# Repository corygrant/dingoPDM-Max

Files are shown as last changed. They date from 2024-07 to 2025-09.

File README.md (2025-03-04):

## dingoPDM-Max
dingoPDM-Max is an Infineon Profet based Power Distribution Module. 

# [**Documentation**](https://corygrant.github.io/dingoPDM/)

# [**Store**](https://dingo-electronics.square.site/product/dingopdm-max/9)

## Disclaimer
Please note that this product has been designed by a hobbyist, not a professional. It is intended for off-road and testing use only. Users should operate the product at their own discretion and risk. The designer explicitly disclaims any responsibility for damage or injury that may result from the use of this product.

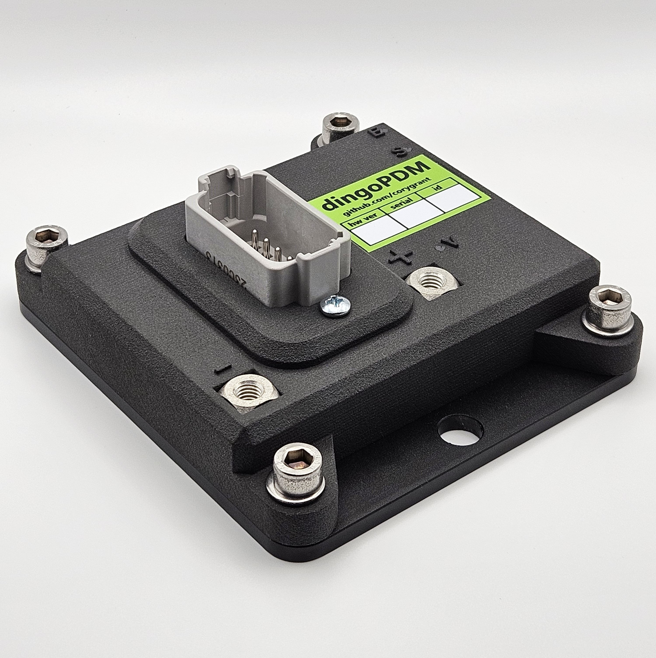
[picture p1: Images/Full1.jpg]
Full1


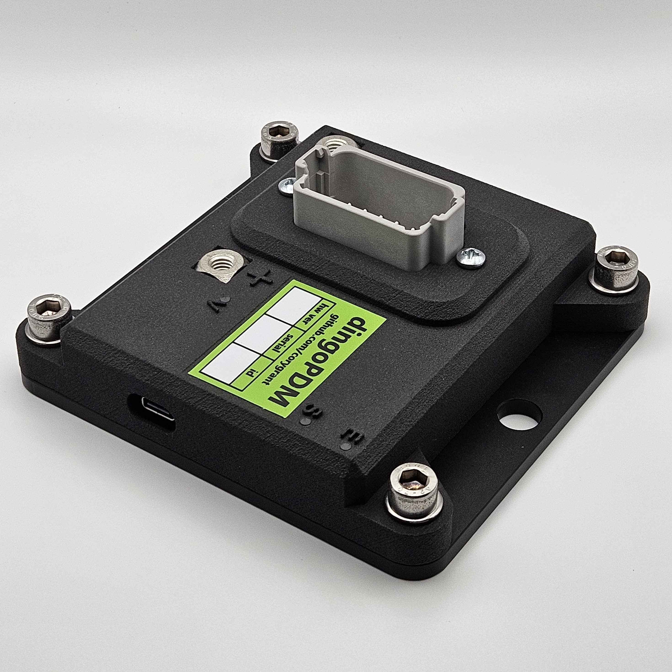
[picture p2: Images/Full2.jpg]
Full2


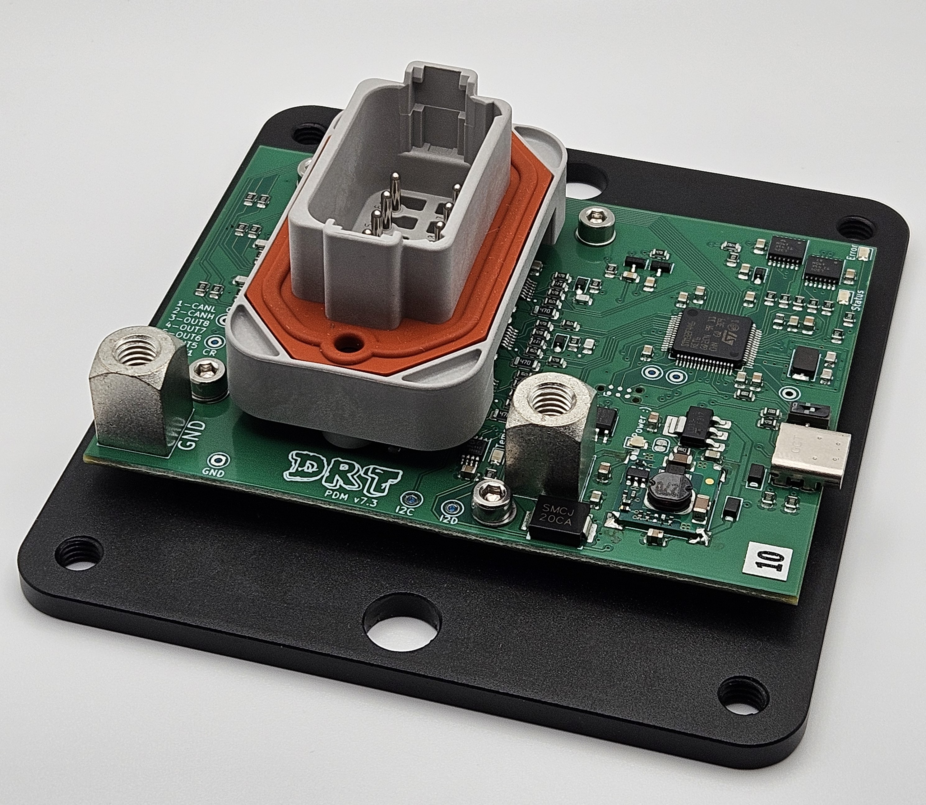
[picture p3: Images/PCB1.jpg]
PCB1


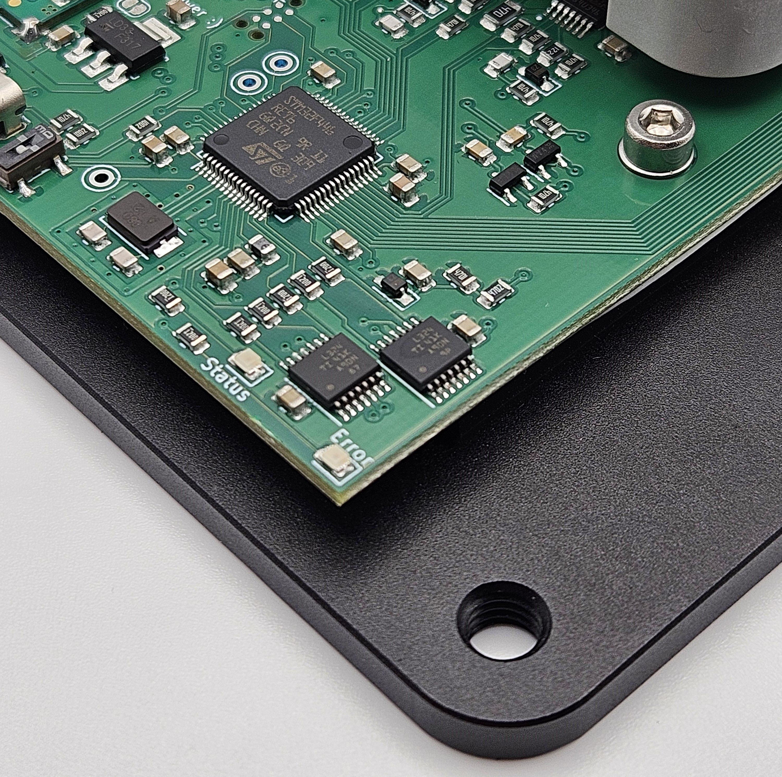
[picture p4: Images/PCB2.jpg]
PCB2


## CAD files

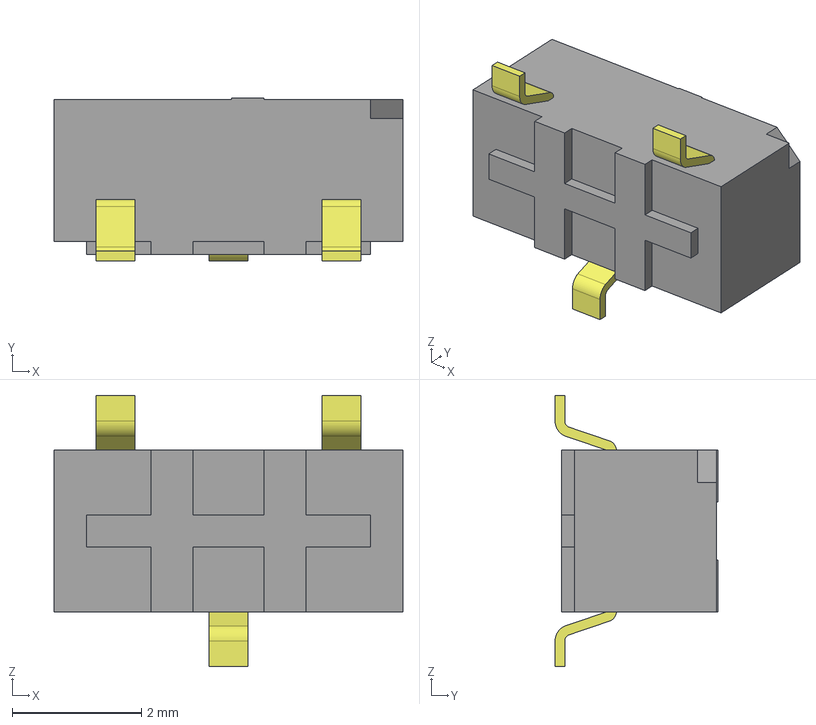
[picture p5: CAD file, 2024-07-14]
dingoPDM-Max/Models/CJS-1200TB.stp
5.40 x 2.52 x 4.20 mm
_CJS_c_12
_CJS Slider_s

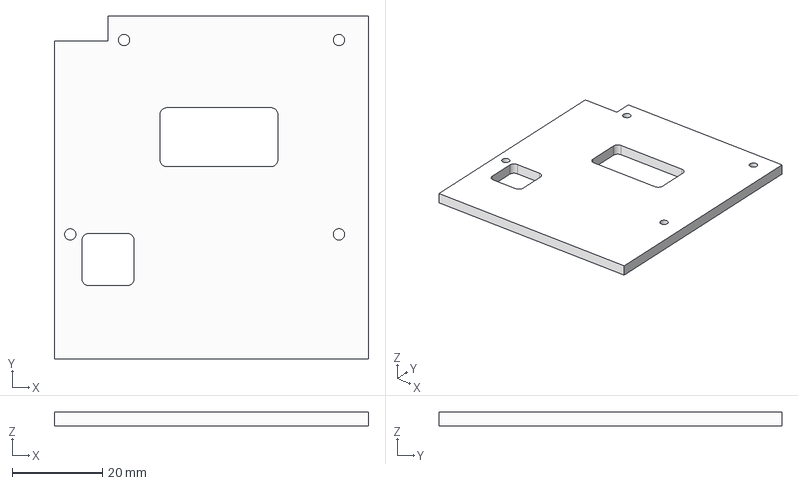
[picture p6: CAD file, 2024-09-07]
Export/V1.2/Case/HeatsinkPlate.step
69.8 x 76.2 x 3.17 mm

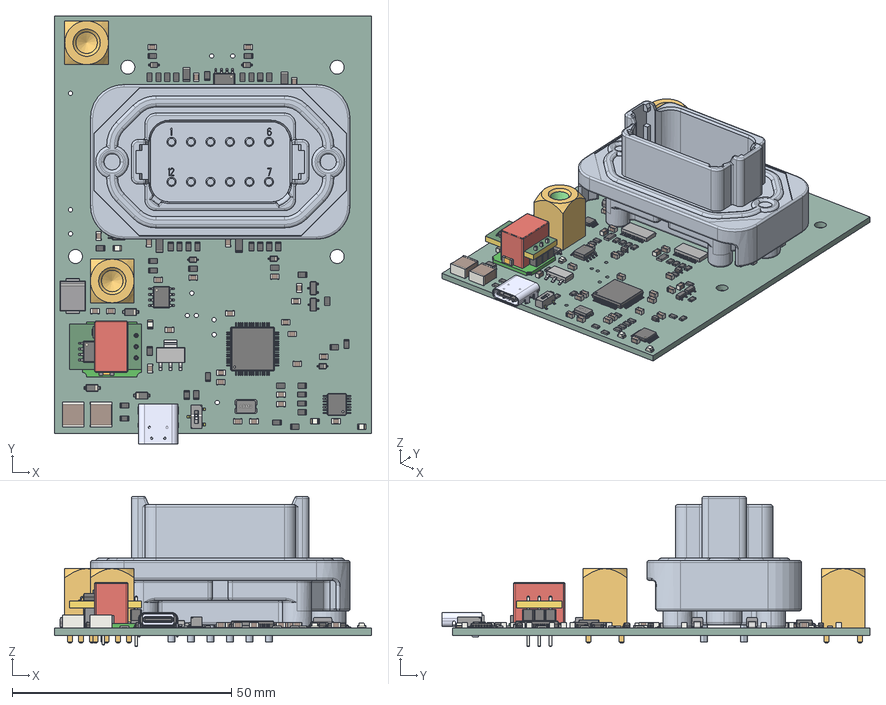
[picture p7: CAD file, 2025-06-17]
Export/V1.2/dingoPDM-Max_V1_2.step
72.4 x 97.6 x 34.3 mm
R_0805_2012Metric x 41
SOIC-8_3.9x4.9mm_P1.27mm x 2
ABM3
C_0805_2012Metric x 38
7461084_Download_STP_7461084_rev1 x 2
MSOP-8_3x3mm_P0.65mm
D_SOD-323 x 5
PG-TSDSO-24-32 x 4
LQFP-64_10x10mm_P0.5mm
c-dt15-12pa-e-3d
CUI_VXO7805-500-M
LED_0805_2012Metric x 4
User Library-SOT23-3
SOT-23 x 2
C_2220_5750Metric x 2
User Library-DO-214AC SMA x 4
USB4085-GF-A--3DModel-STEP-56544
Converter_DCDC_Murata_OKI-78SR_Horizontal
R_1206_3216Metric x 4
D_SOD-123 x 3
User Library-sot-223
User Library-DO-214AB SMC
_CJS_c_12
_CJS Slider_s
Converter_DCDC_TRACO_TSR-1_THT
TSSOP-14_4.4x5mm_P0.65mm
dingoPDM-Max_PCB

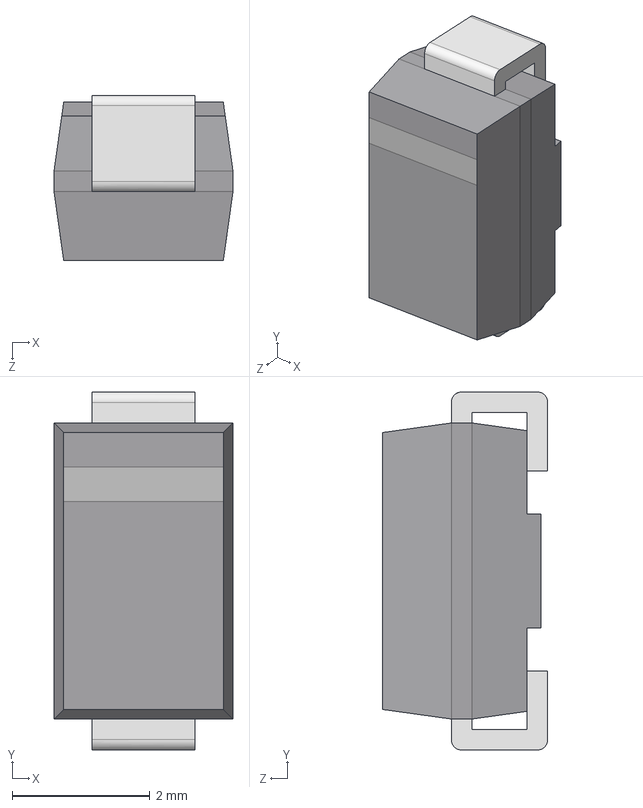
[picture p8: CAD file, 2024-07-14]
dingoPDM-Max/Models/User Library-DO-214AC SMA.STEP
2.60 x 5.20 x 2.40 mm

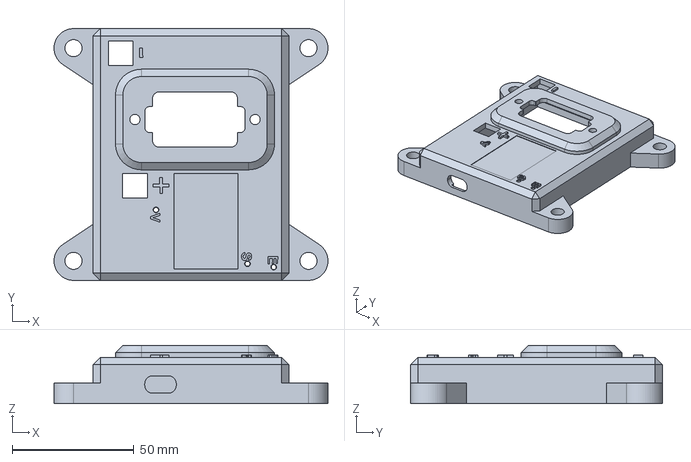
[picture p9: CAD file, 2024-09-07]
Export/V1.2/Case/Case.step
112.4 x 103.3 x 23.9 mm

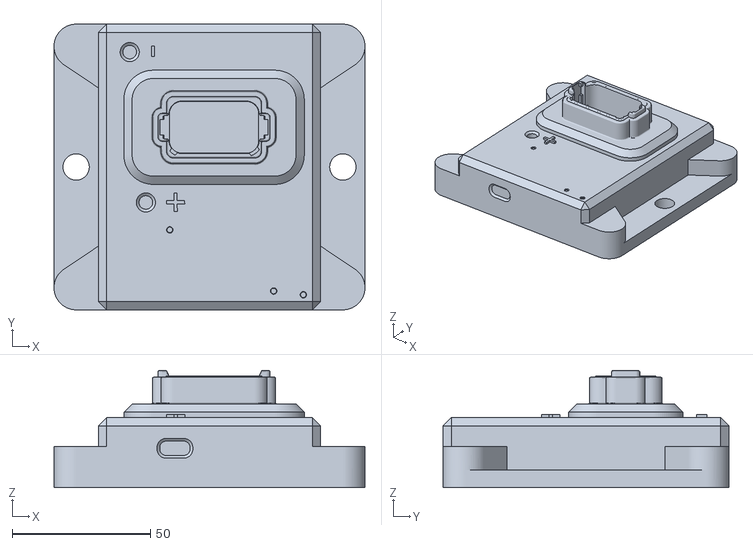
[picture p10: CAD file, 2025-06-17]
Export/V1.2/DingoPDM_V7_WiringAid.stl
112.4 x 103.2 x 42.3

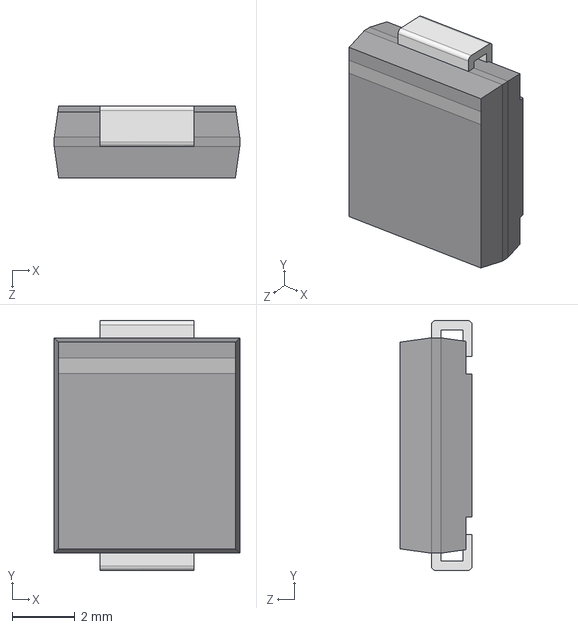
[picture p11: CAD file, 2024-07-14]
dingoPDM-Max/Models/User Library-DO-214AB SMC.STEP
5.90 x 7.95 x 2.30 mm

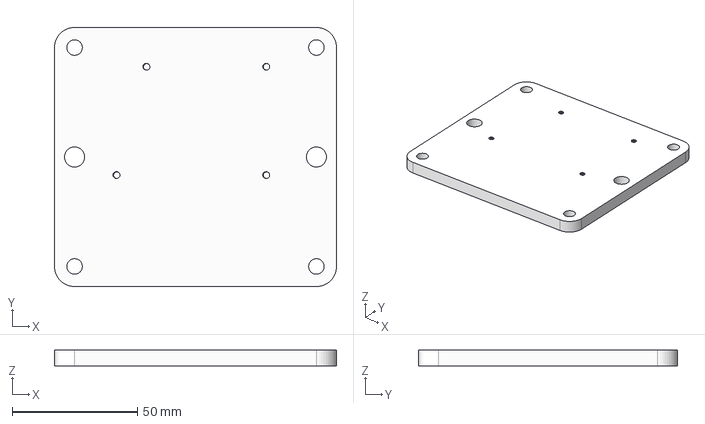
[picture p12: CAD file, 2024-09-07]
Export/V1.2/Case/Baseplate.step
112.4 x 103.2 x 6.35 mm

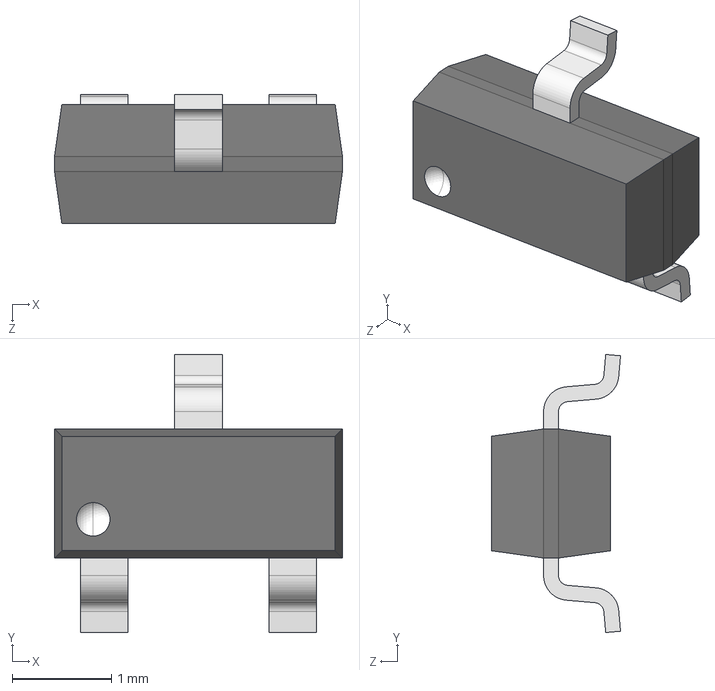
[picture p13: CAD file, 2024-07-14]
dingoPDM-Max/Models/User Library-SOT23-3.step
2.90 x 2.80 x 1.30 mm

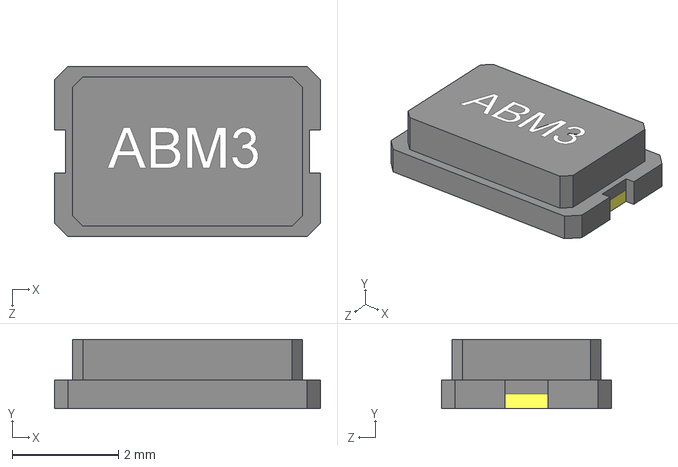
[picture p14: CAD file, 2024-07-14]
dingoPDM-Max/Models/ABM3.STEP
5.00 x 1.30 x 3.20 mm

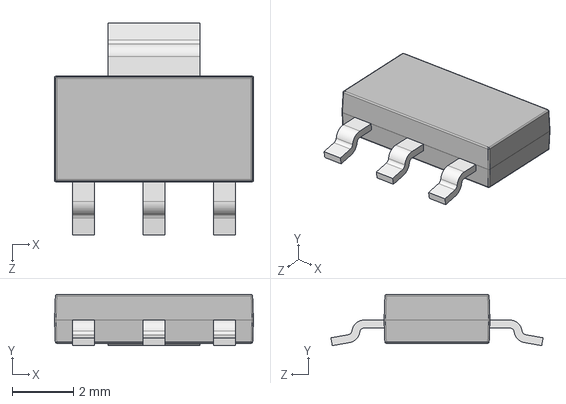
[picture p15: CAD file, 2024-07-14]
dingoPDM-Max/Models/User Library-sot-223.STEP
6.50 x 1.67 x 6.93 mm

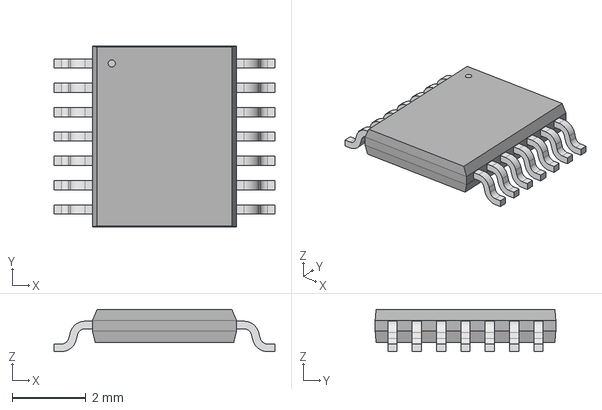
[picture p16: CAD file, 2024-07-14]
dingoPDM-Max/Models/PG-TSDSO-14_INF.step
5.99 x 4.90 x 1.15 mm

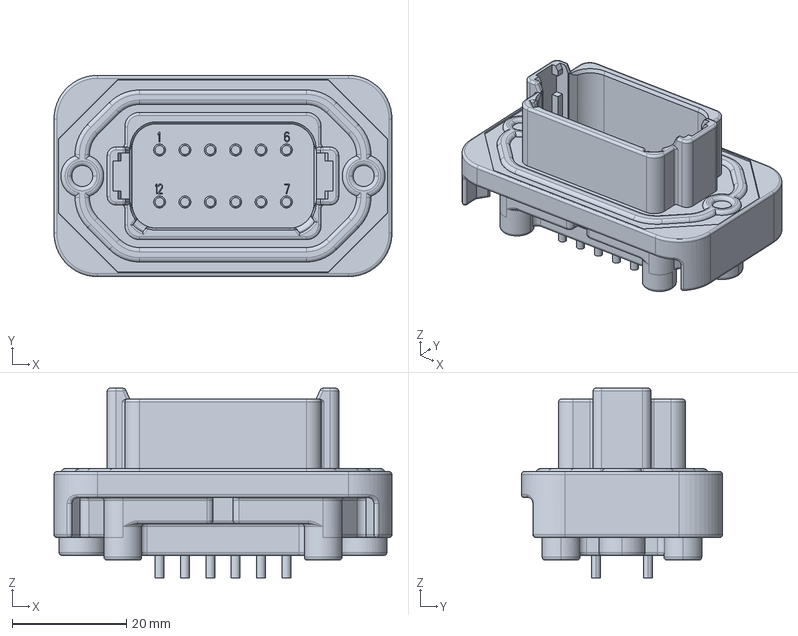
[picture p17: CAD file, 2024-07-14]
dingoPDM-Max/Models/c-dt15-12pa-e-3d.stp
59.2 x 35.3 x 33.2 mm

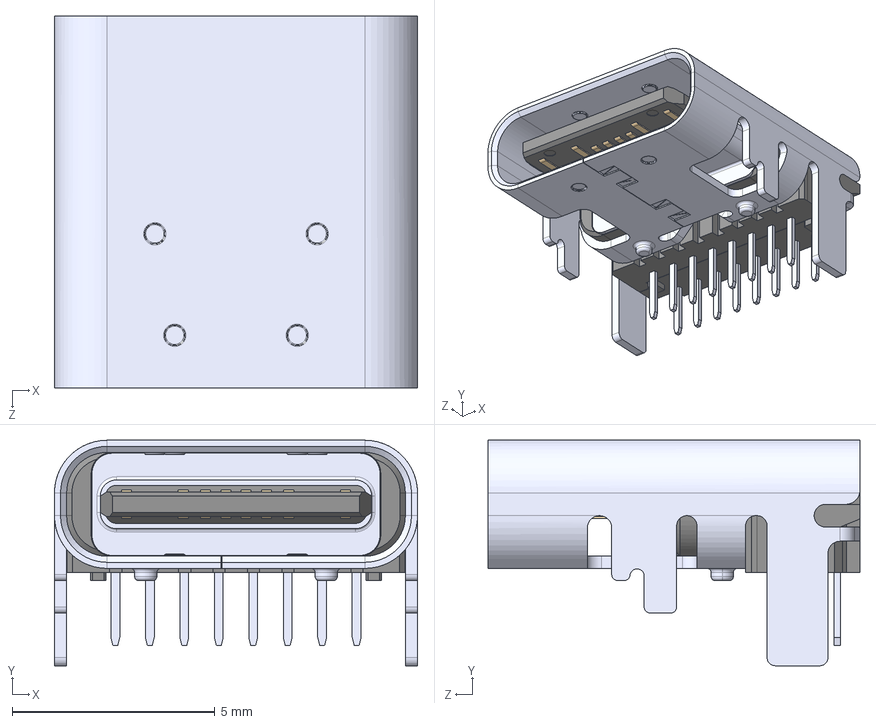
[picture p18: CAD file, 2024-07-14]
dingoPDM-Max/Models/USB4085-GF-A--3DModel-STEP-56544.STEP
8.95 x 5.56 x 9.17 mm

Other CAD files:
dingoPDM-Max/Models/7461084_Download_STP_7461084_rev1.stp

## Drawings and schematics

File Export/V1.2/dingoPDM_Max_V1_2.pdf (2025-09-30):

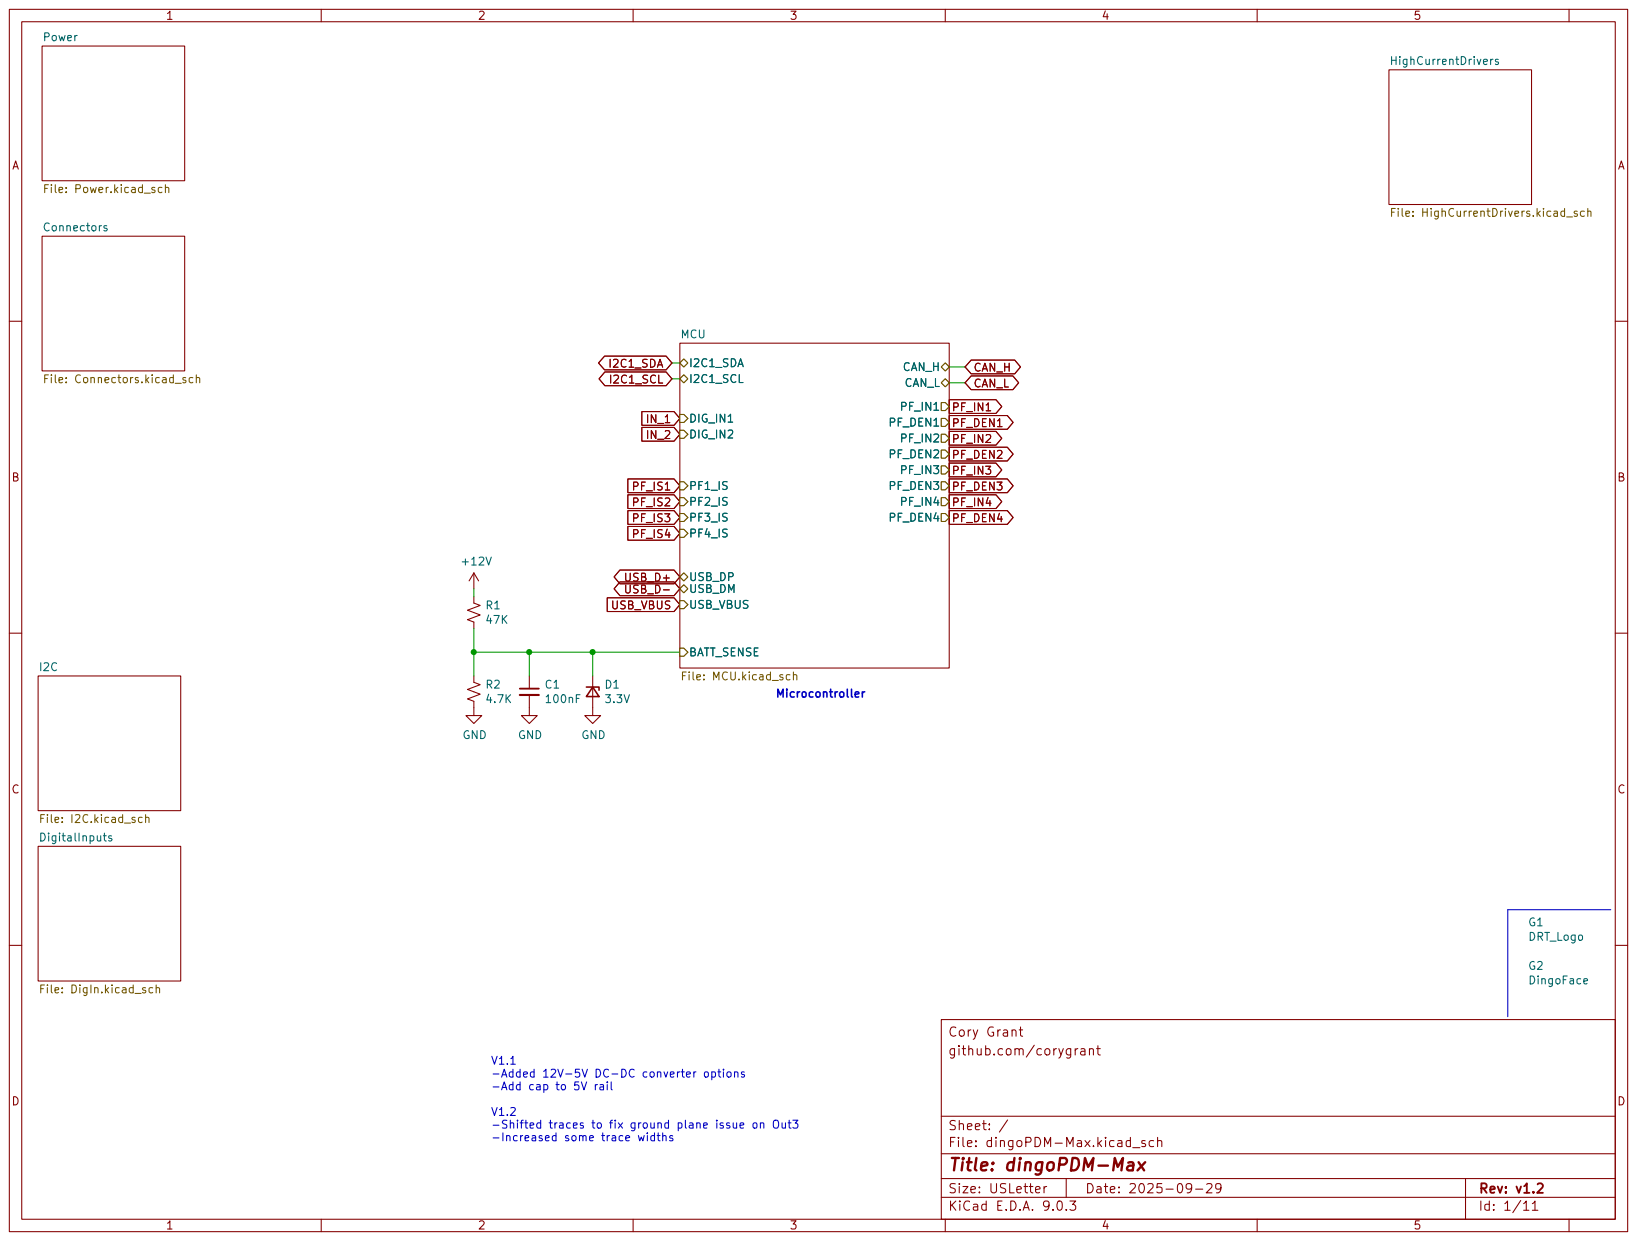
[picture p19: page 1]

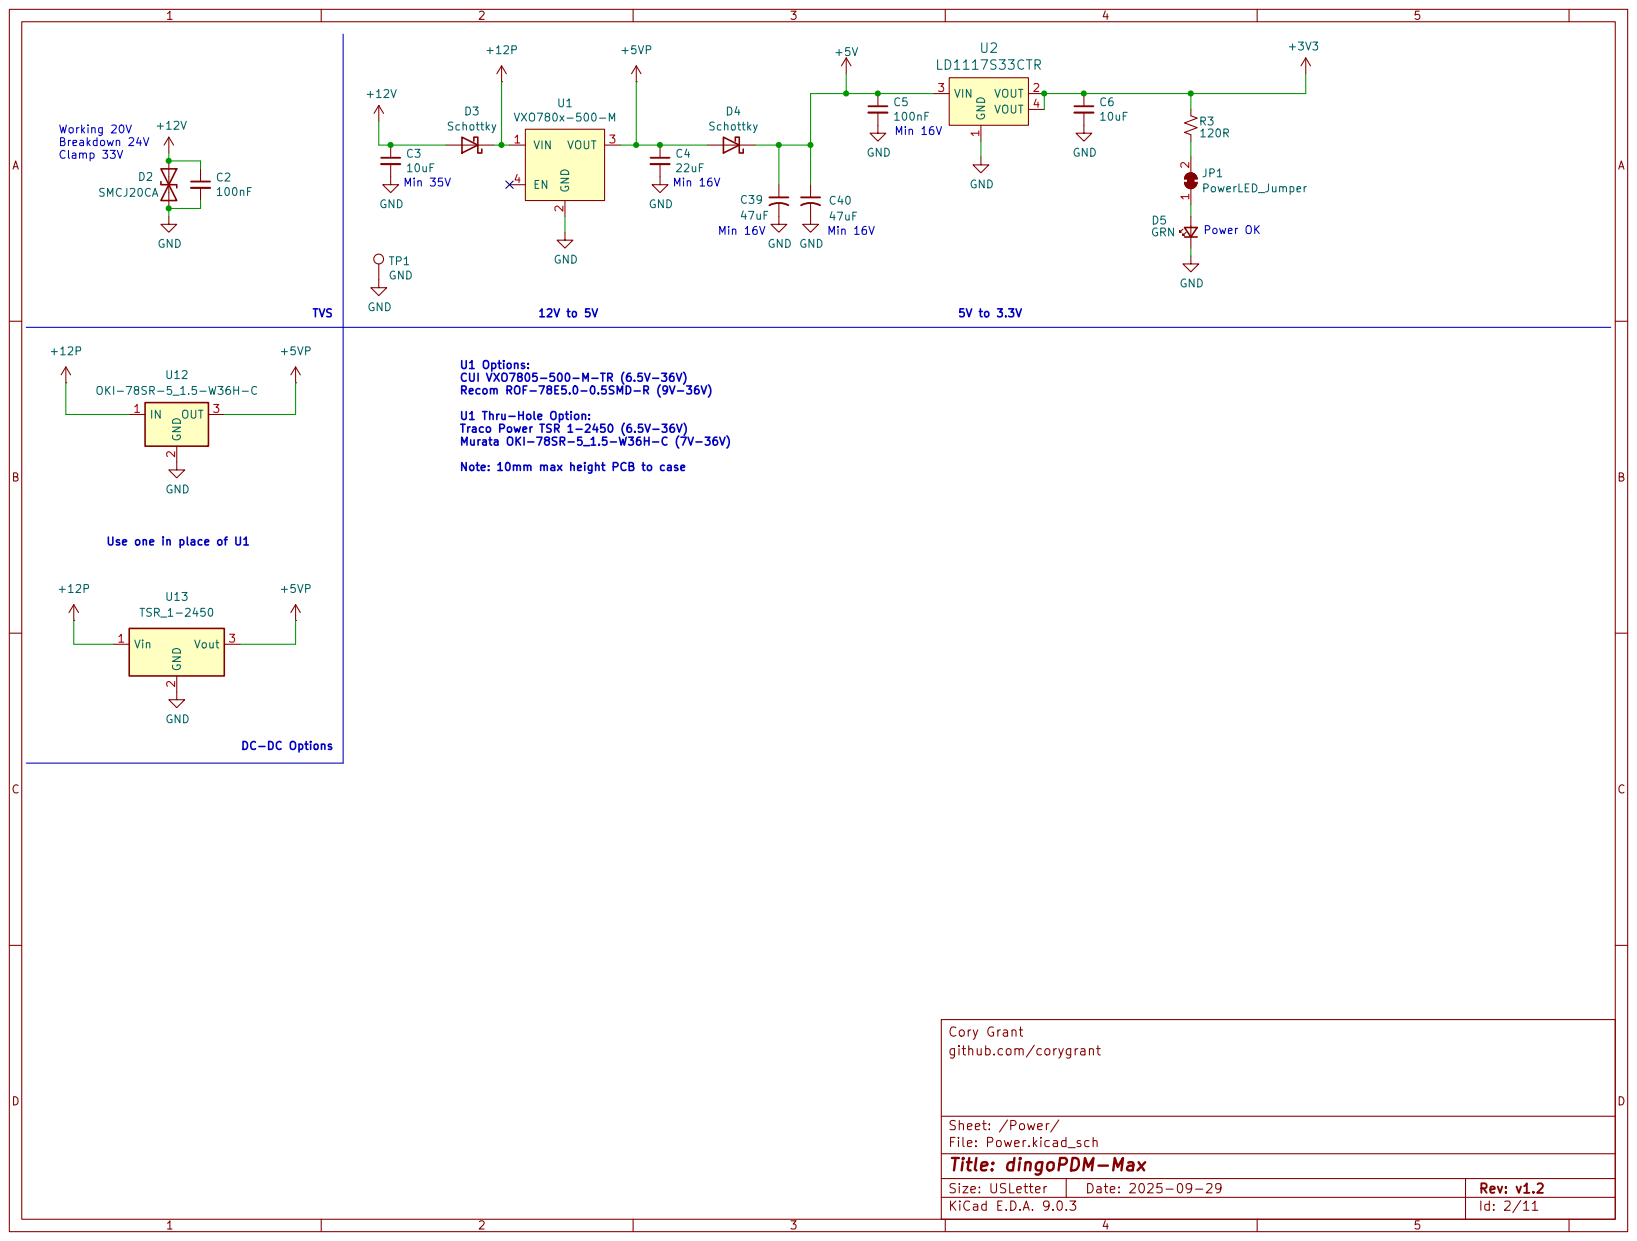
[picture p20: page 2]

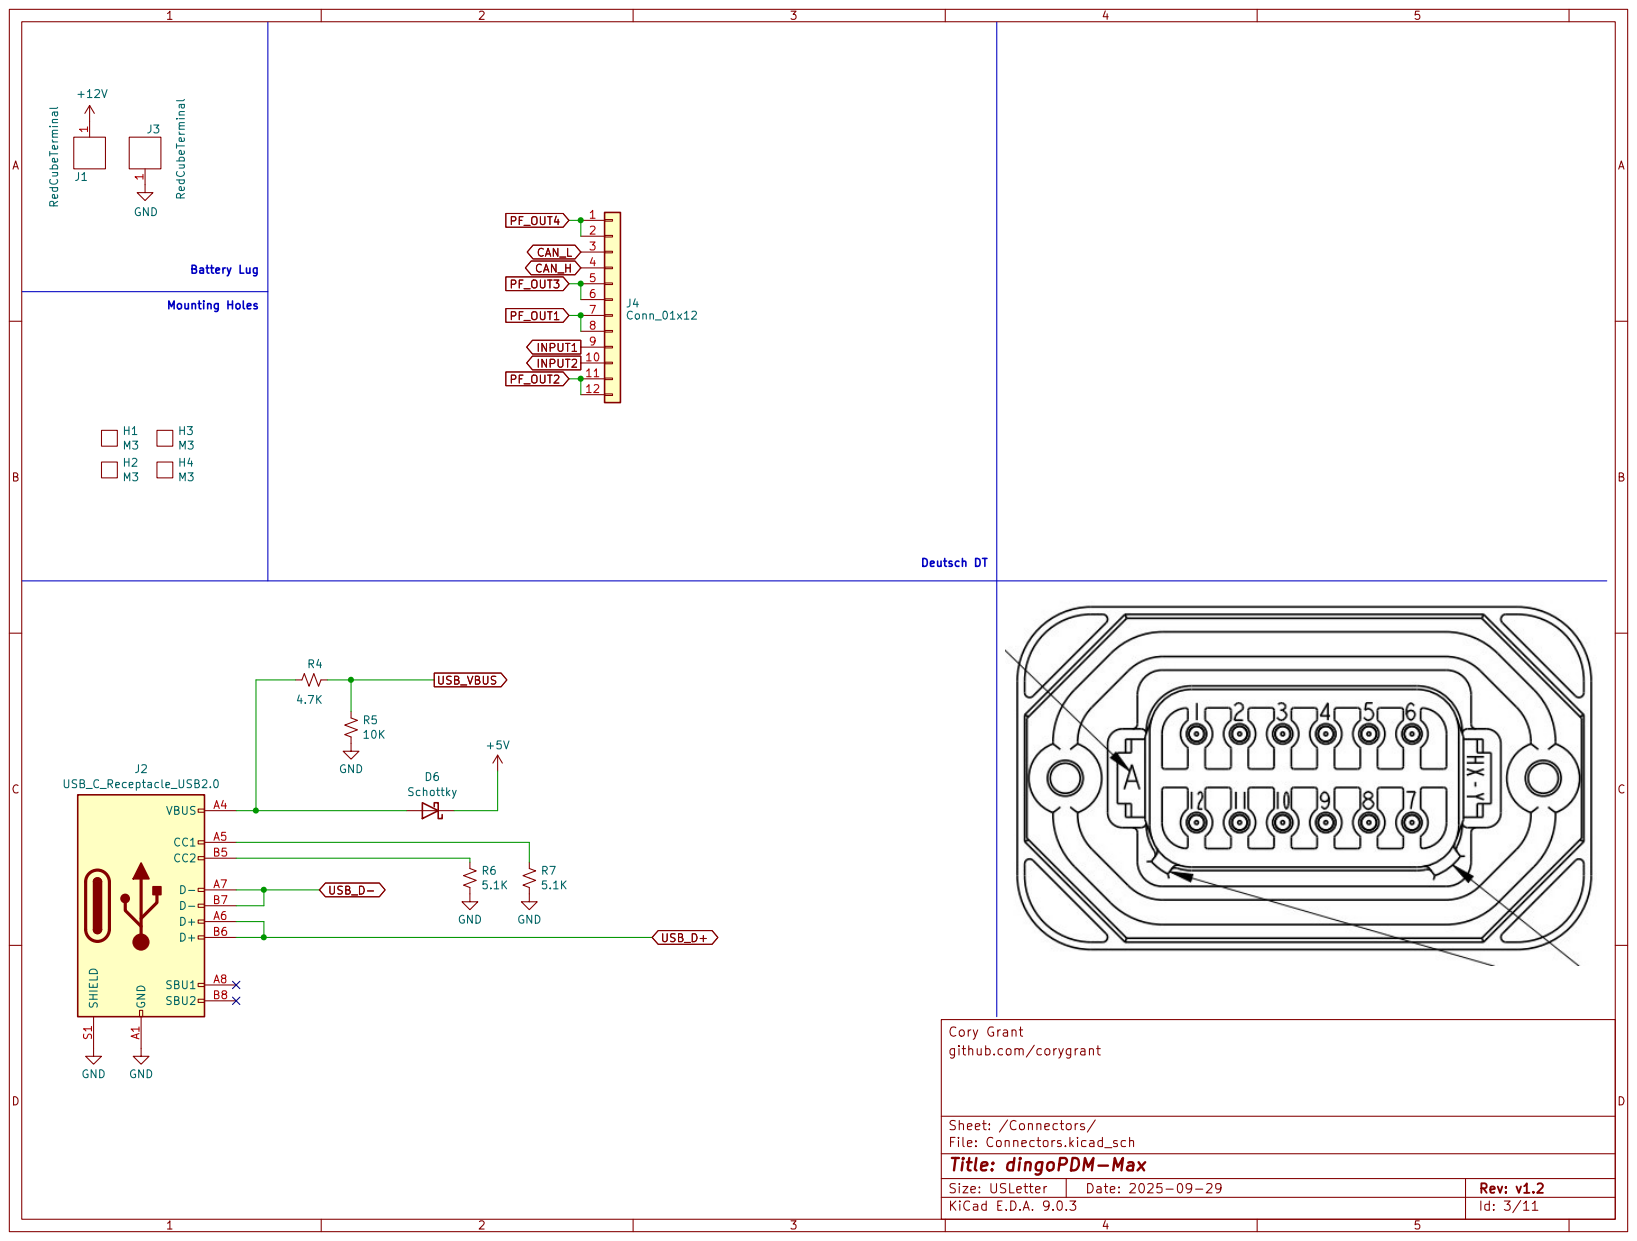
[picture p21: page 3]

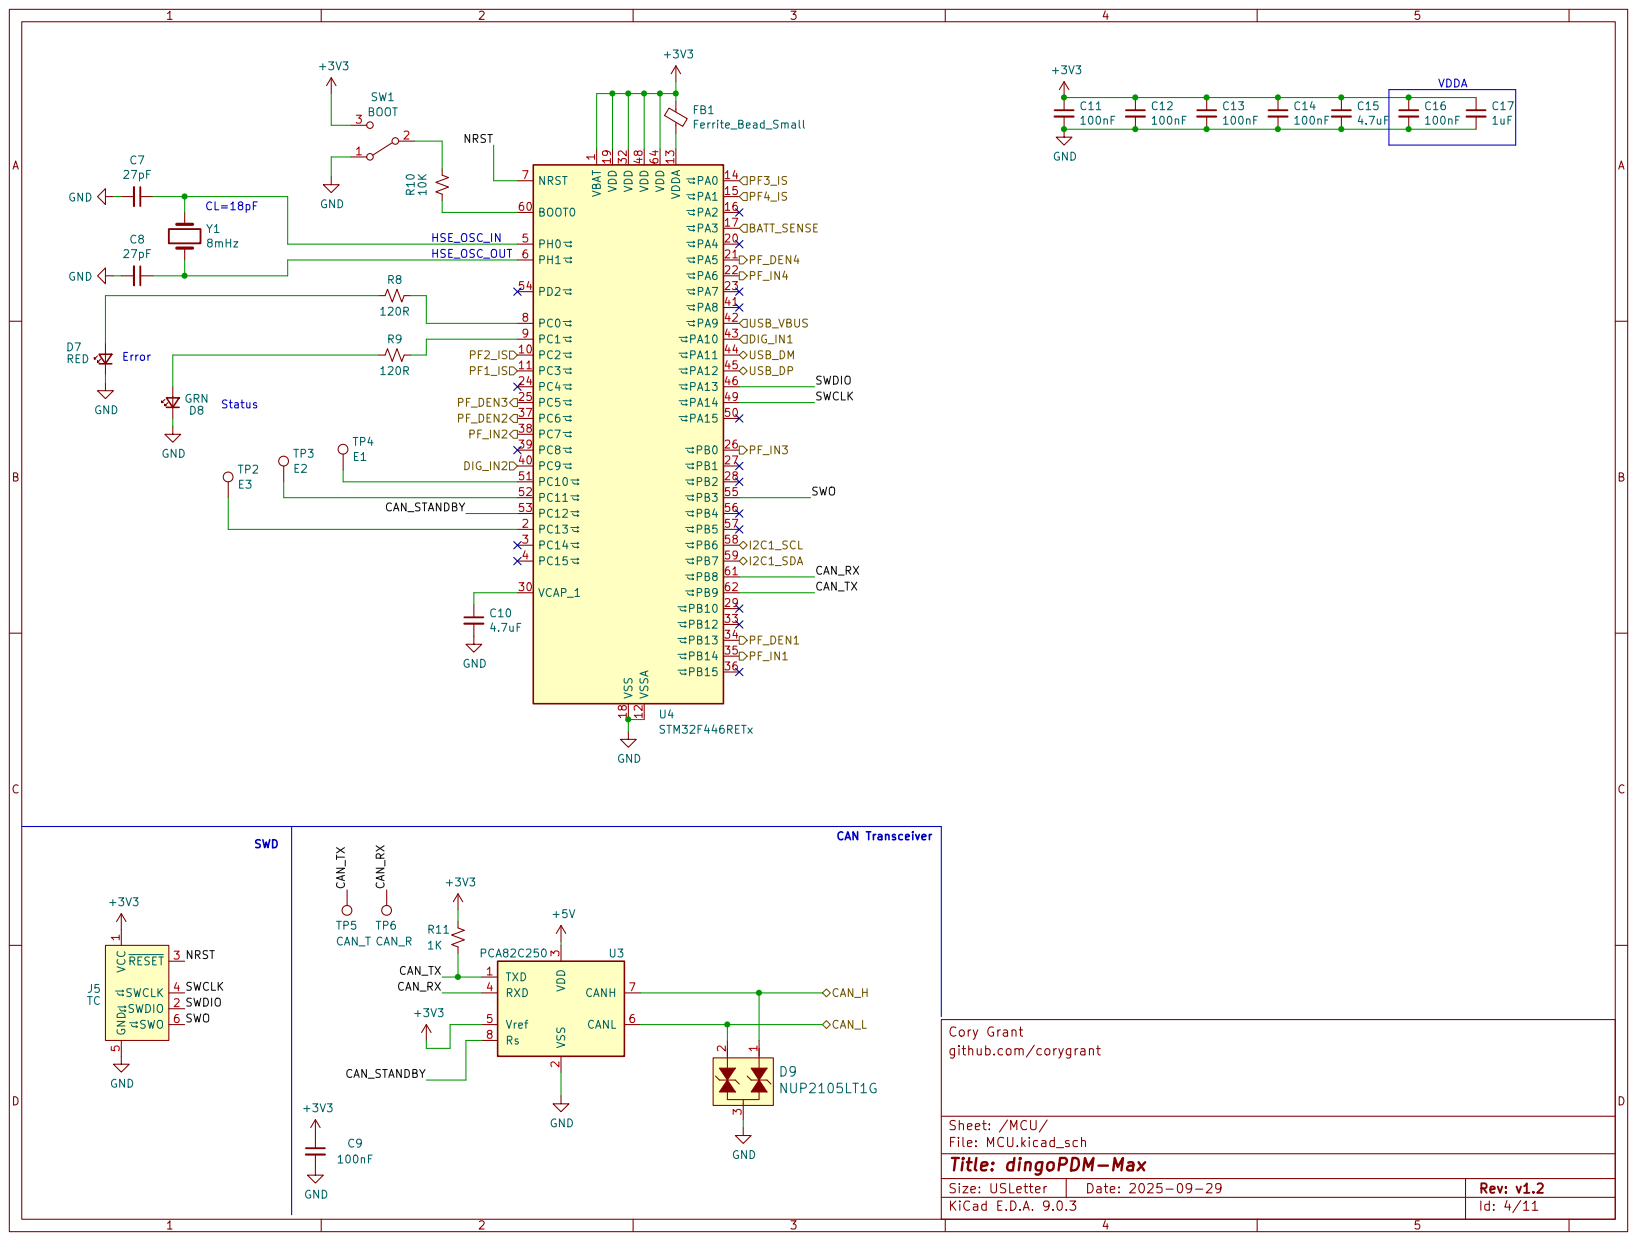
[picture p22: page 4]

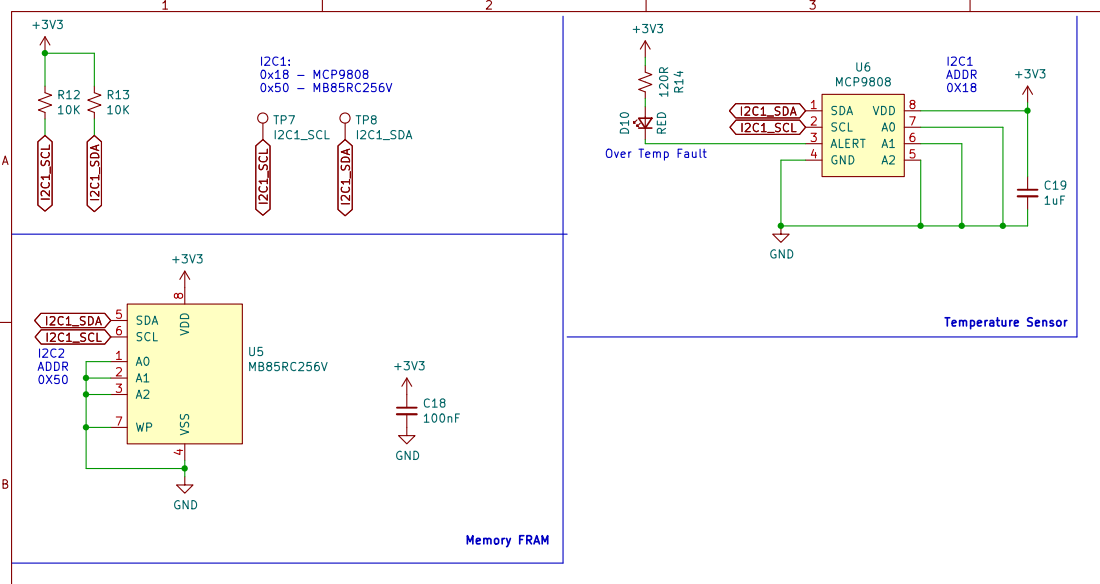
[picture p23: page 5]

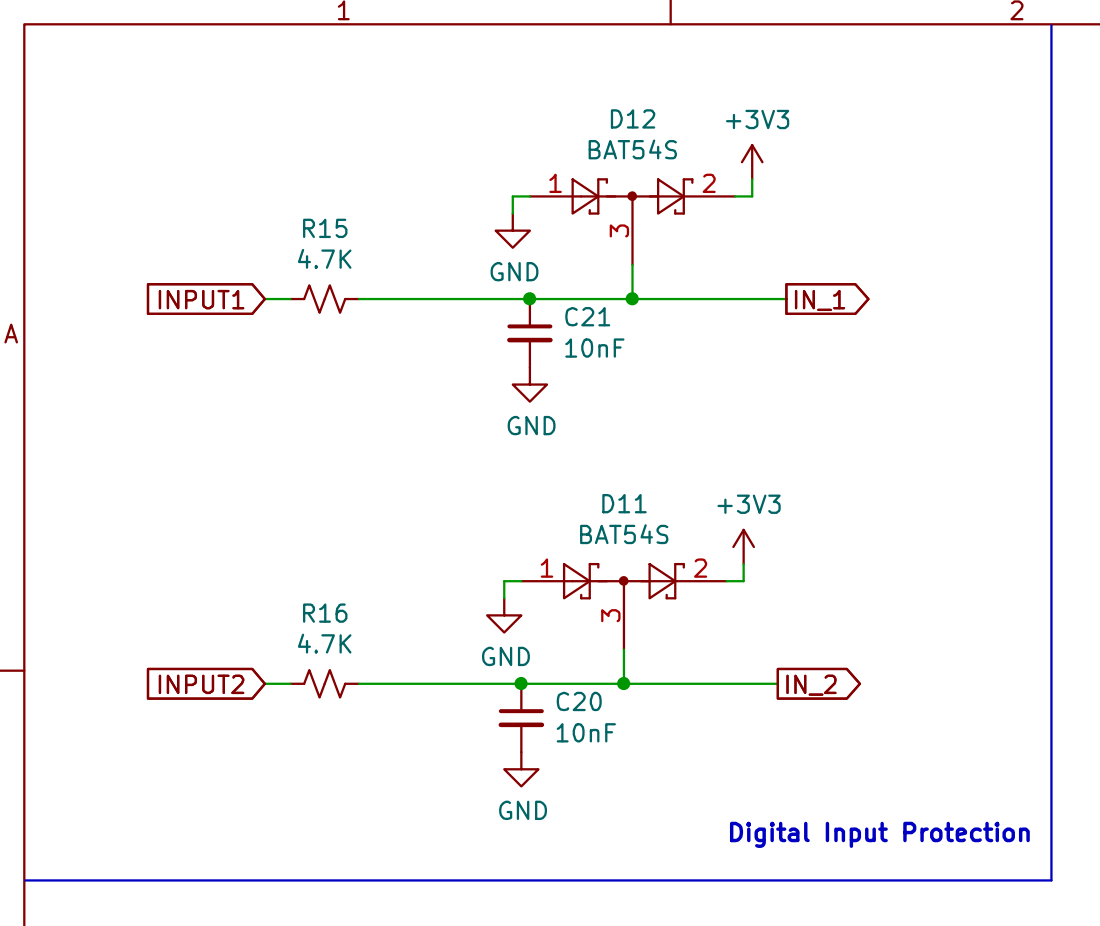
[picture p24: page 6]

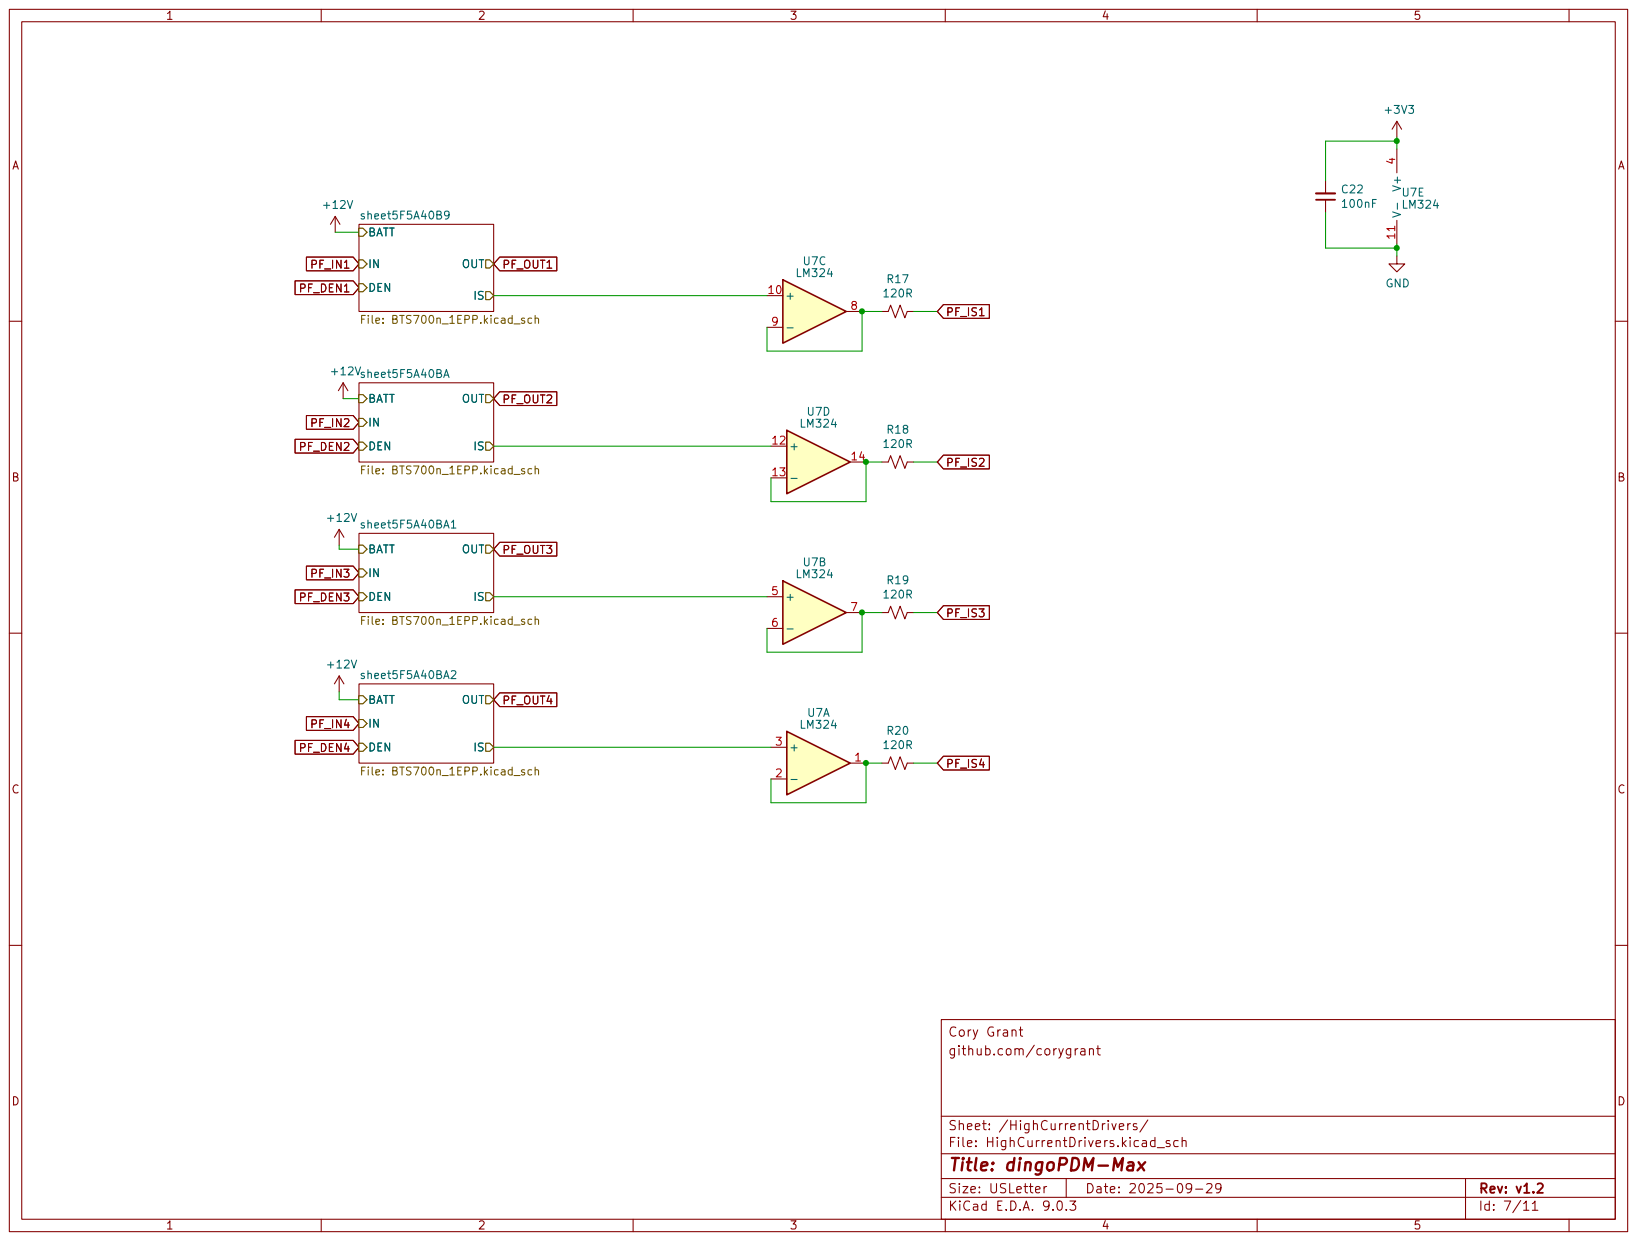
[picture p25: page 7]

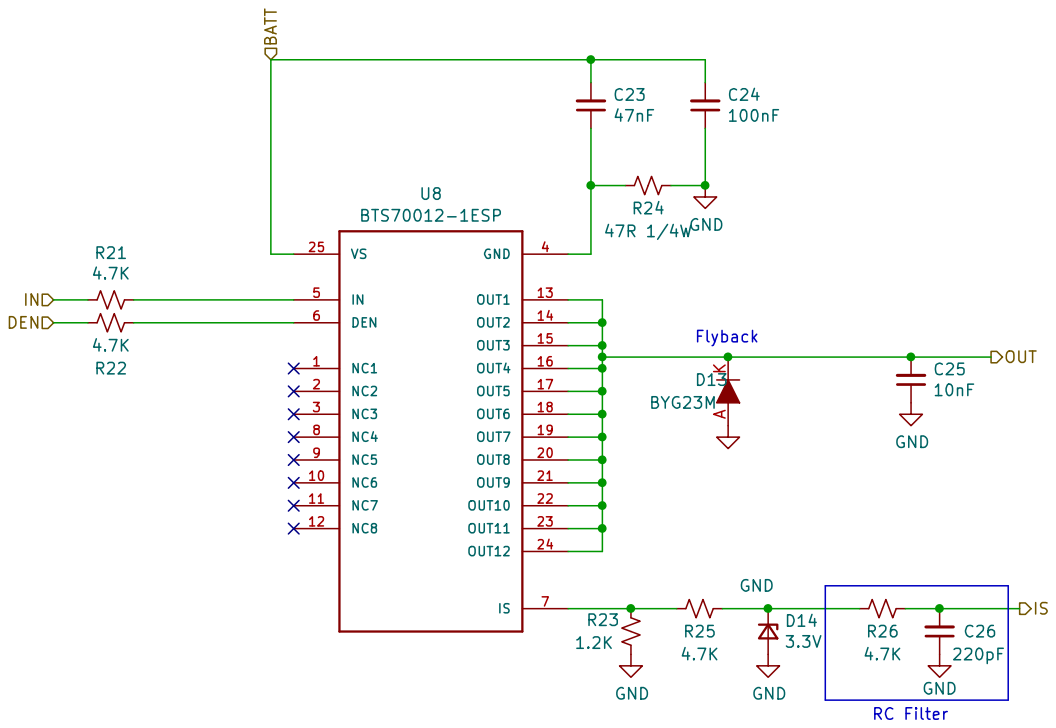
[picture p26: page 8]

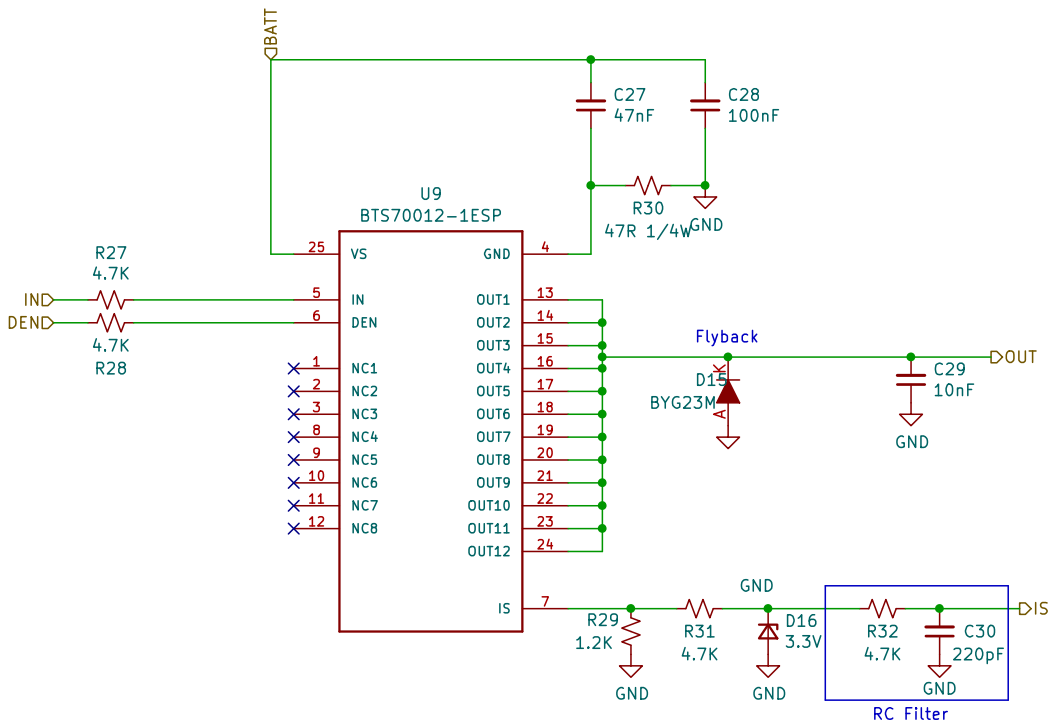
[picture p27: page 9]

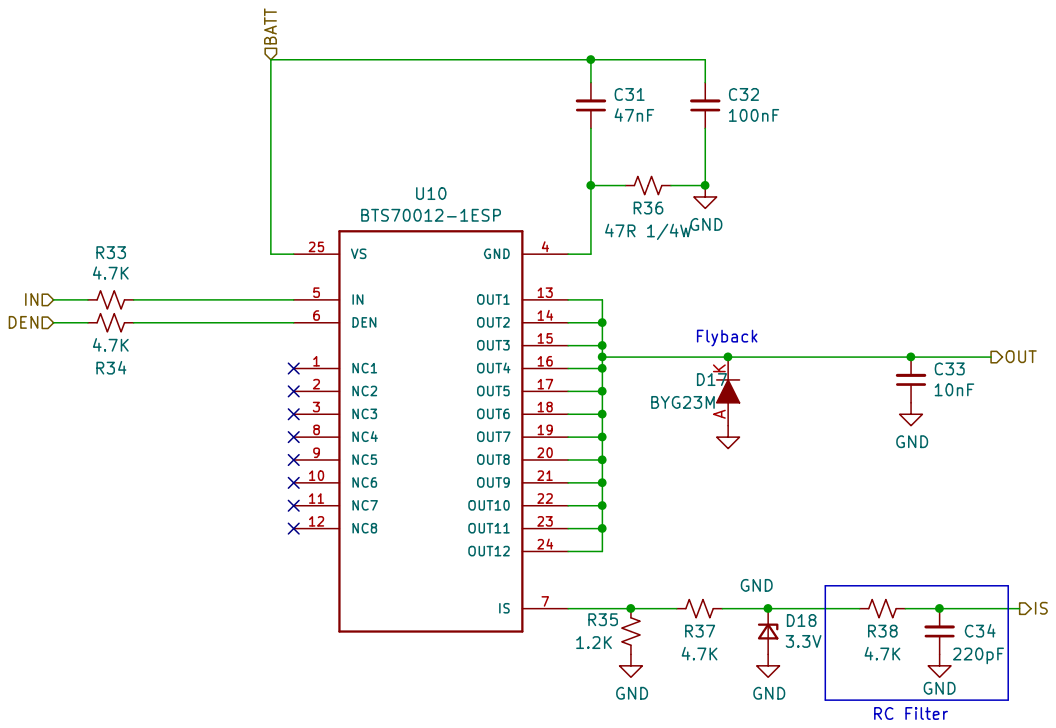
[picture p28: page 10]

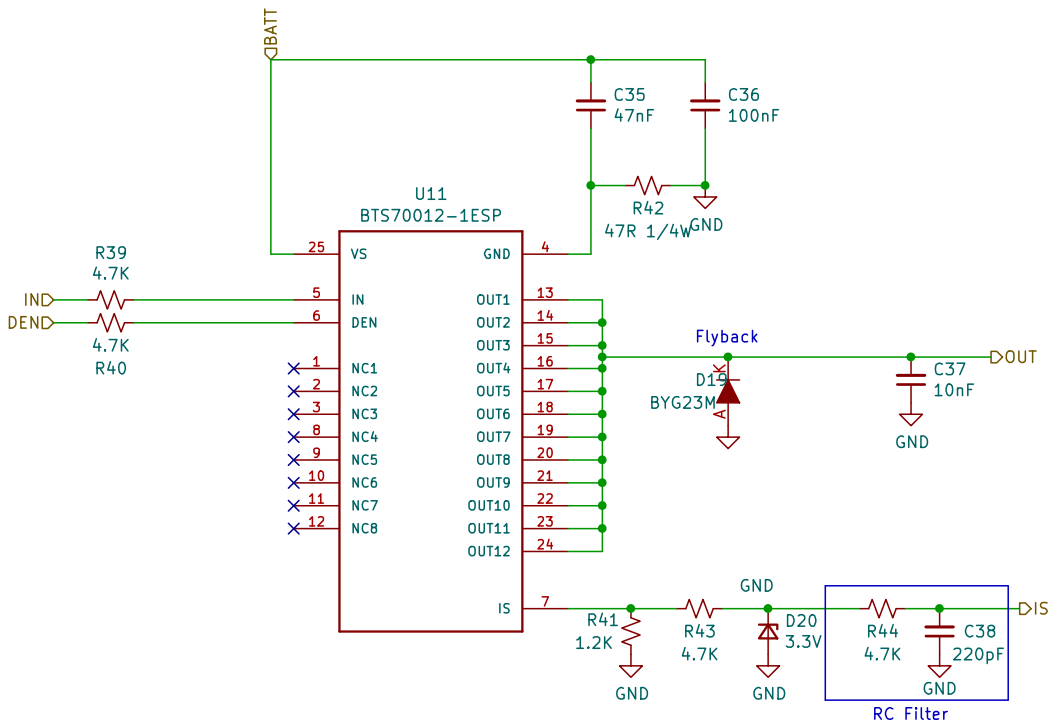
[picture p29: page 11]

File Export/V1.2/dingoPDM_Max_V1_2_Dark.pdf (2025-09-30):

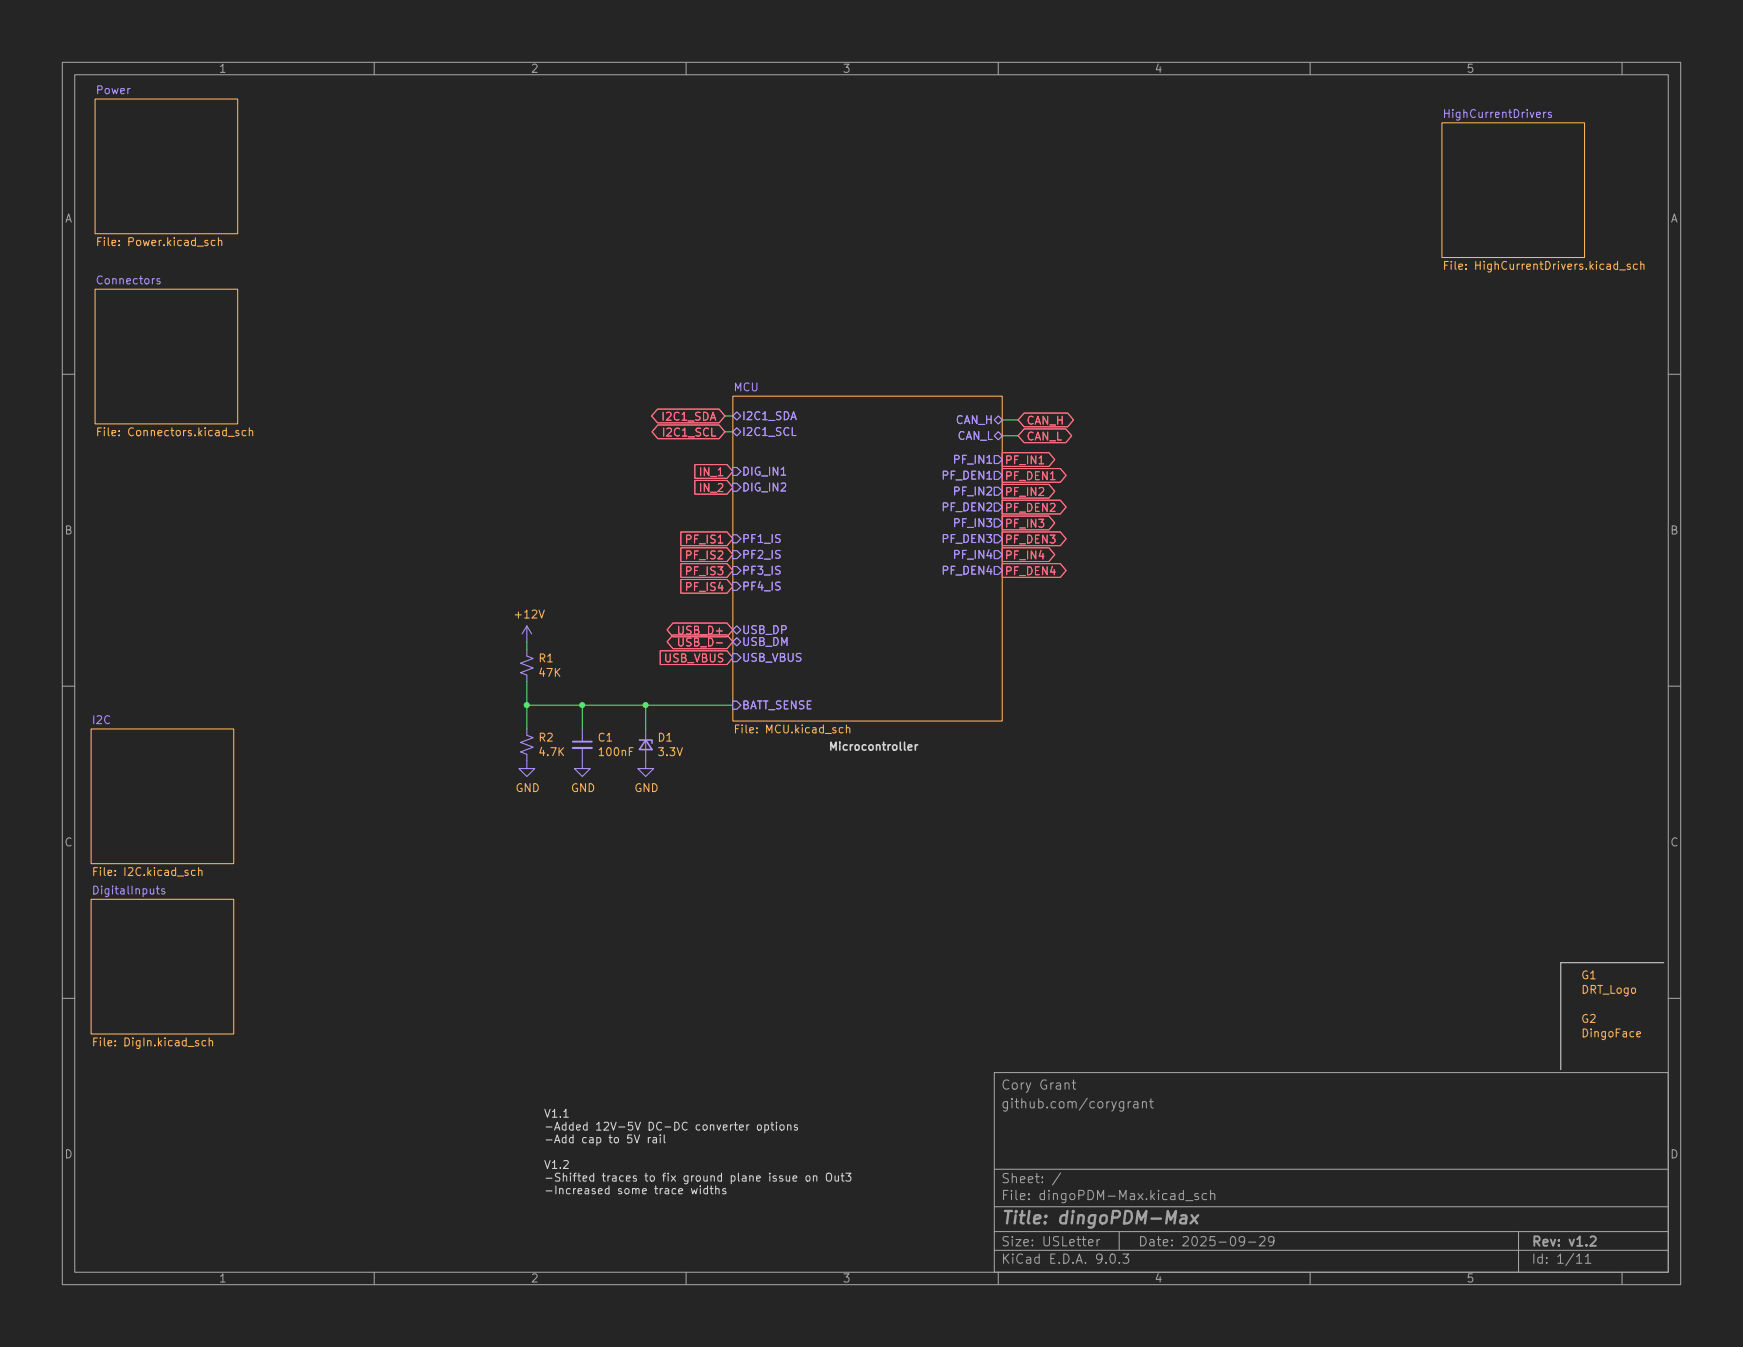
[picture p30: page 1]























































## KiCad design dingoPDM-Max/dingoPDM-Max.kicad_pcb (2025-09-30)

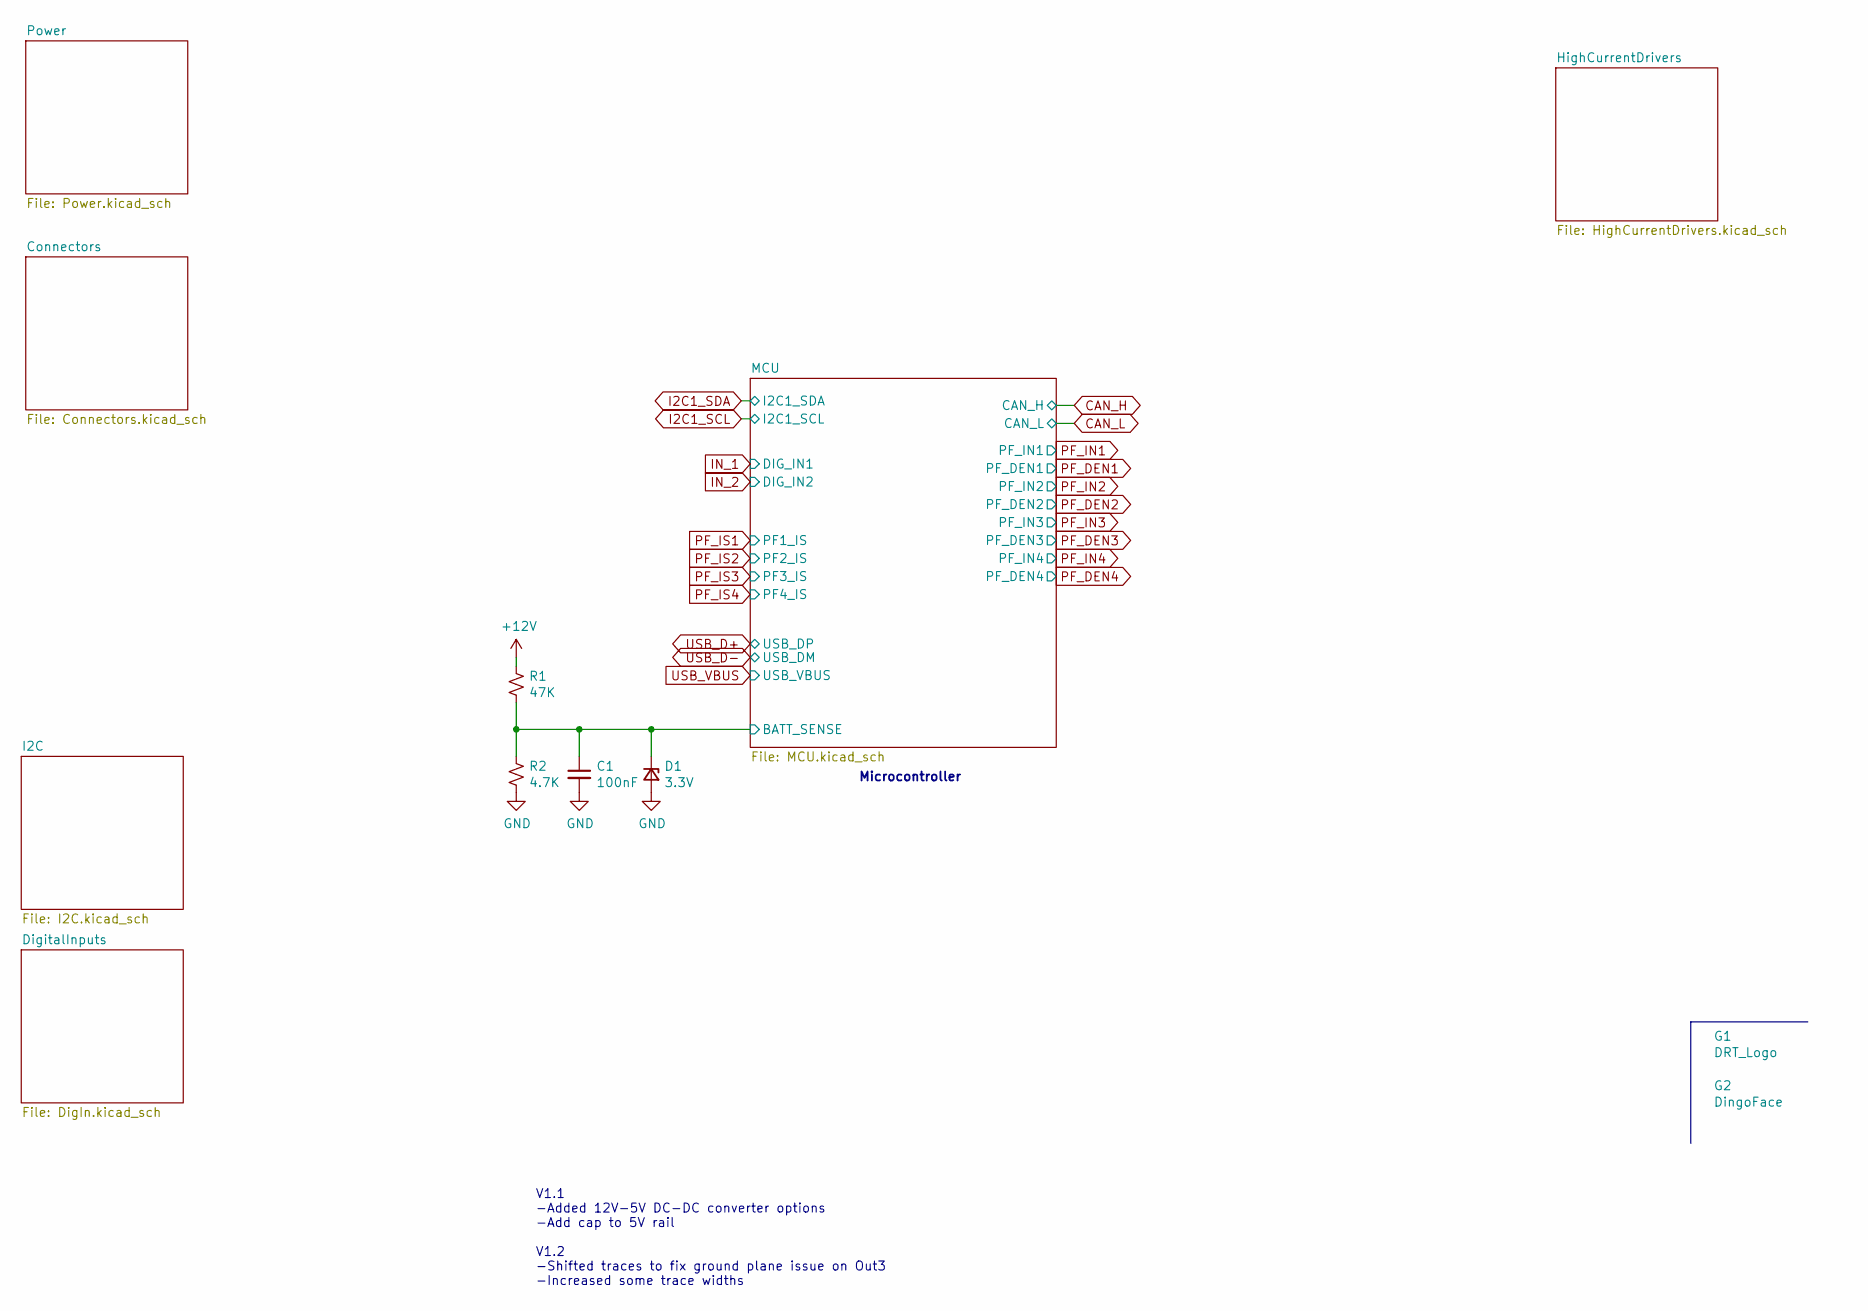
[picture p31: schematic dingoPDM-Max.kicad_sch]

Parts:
C1: 100nF; C_0805_2012Metric; Digi-Key_PN 478-1395-1-ND
D1: 3.3V; D_SOD-323_HandSoldering; Digi-Key_PN 1727-5150-1-ND
G1: DRT_Logo; DRTLogo
G2: DingoFace; DingoFaceNoFill
R1: 47K; R_0805_2012Metric; Digi-Key_PN 311-47.0KCRCT-ND
R2: 4.7K; R_0805_2012Metric; Digi-Key_PN 311-4.70KCRCT-ND

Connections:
+12V: R1.1; also elsewhere on the board
/MCU/BATT_SENSE: C1.1, D1.1 (K), R1.2, R2.1; also elsewhere on the board
GND: C1.2, D1.2 (A), R2.2; also elsewhere on the board

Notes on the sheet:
Microcontroller
V1.1 -Added 12V-5V DC-DC converter options -Add cap to 5V rail V1.2 -Shifted traces to fix ground plane issue on Out3 -Increased some trace widths

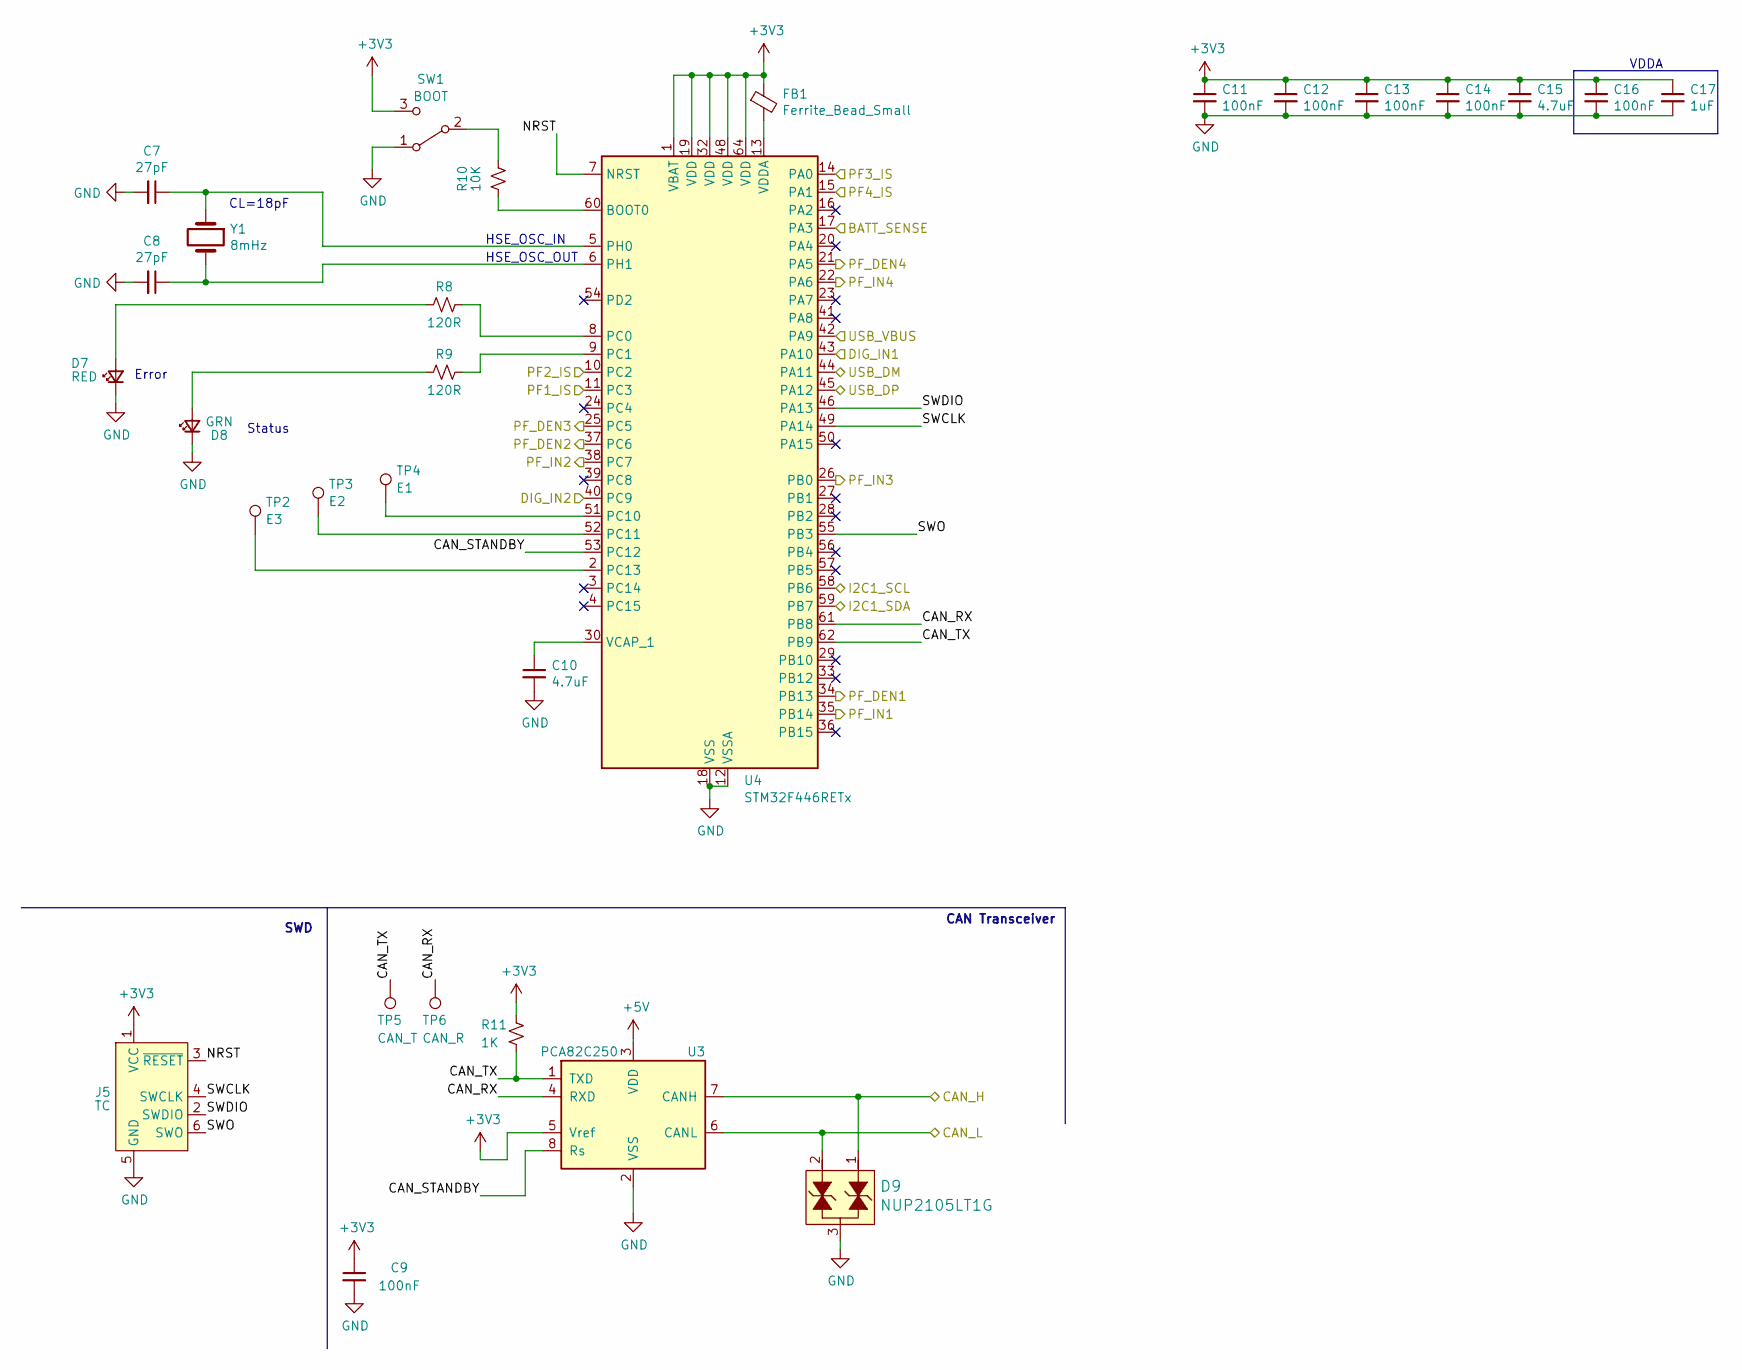
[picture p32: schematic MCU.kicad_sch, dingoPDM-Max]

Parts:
C7, C8: 27pF; C_0805_2012Metric; Digi-Key_PN 478-10518-1-ND
C9, C11, C12, C13, C14, C16: 100nF; C_0805_2012Metric; Digi-Key_PN 478-1395-1-ND
C10, C15: 4.7uF; C_0805_2012Metric; Digi-Key_PN 1276-2873-1-ND
C17: 1uF; C_0805_2012Metric; Digi-Key_PN 311-1365-1-ND
D7: RED; LED_0805_2012Metric; Digi-Key_PN 475-1278-1-ND
D8: GRN; LED_0805_2012Metric; Digi-Key_PN 475-1410-1-ND
D9: NUP2105LT1G; SOT-23-3; Digi-Key_PN NUP2105LT1GOSCT-ND
FB1: Ferrite_Bead_Small; R_0805_2012Metric; Digi-Key_PN 490-1054-1-ND
J5: TC; Tag-Connect_TC2030-IDC-NL_2x03_P1.27mm_Vertical
R8, R9: 120R; R_0805_2012Metric; Digi-Key_PN 311-120CRCT-ND
R10: 10K; R_0805_2012Metric; Digi-Key_PN 311-10.0KCRDKR-ND
R11: 1K; R_0805_2012Metric; Digi-Key_PN 311-1.0KARCT-ND
SW1: BOOT; CJS-1200TB; Digi-Key_PN 563-CJS-1200TB1CT-ND
TP2: E3; TestPoint_Keystone_5000-5004_Miniature
TP3: E2; TestPoint_Keystone_5000-5004_Miniature
TP4: E1; TestPoint_Keystone_5000-5004_Miniature
TP5: CAN_T; TestPoint_Keystone_5000-5004_Miniature
TP6: CAN_R; TestPoint_Keystone_5000-5004_Miniature
U3: PCA82C250; SOIC-8_3.9x4.9mm_P1.27mm; Digi-Key_PN 568-10316-1-ND
U4: STM32F446RETx; LQFP-64_10x10mm_P0.5mm; Digi-Key_PN 497-15376-ND
Y1: 8mHz; Crystal_SMD_5032-2Pin_5.0x3.2mm_HandSoldering; Digi-Key_PN 535-10630-1-ND

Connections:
+3V3: C9.1, C11.1, C12.1, C13.1, C14.1, C15.1, C16.1, C17.1, FB1.1, J5.1 (VCC), R11.2, SW1.3 (C), U3.5 (Vref), U4.1 (VBAT), U4.19 (VDD), U4.32 (VDD), U4.48 (VDD), U4.64 (VDD); also elsewhere on the board
+5V: U3.3 (VDD); also elsewhere on the board
/MCU/BATT_SENSE: U4.17 (PA3); also elsewhere on the board
/MCU/CAN_RX: TP6.1, U3.4 (RXD), U4.61 (PB8)
/MCU/CAN_STANDBY: U3.8 (Rs), U4.53 (PC12)
/MCU/CAN_TX: R11.1, TP5.1, U3.1 (TXD), U4.62 (PB9)
/MCU/NRST: J5.3 (~RESET), U4.7 (NRST)
/MCU/SWCLK: J5.4 (SWCLK), U4.49 (PA14)
/MCU/SWDIO: J5.2 (SWDIO), U4.46 (PA13)
/MCU/SWO: J5.6 (SWO), U4.55 (PB3)
CAN_H: D9.1, U3.7 (CANH); also elsewhere on the board
CAN_L: D9.2, U3.6 (CANL); also elsewhere on the board
GND: C7.2, C8.2, C9.2, C10.2, C11.2, C12.2, C13.2, C14.2, C15.2, C16.2, C17.2, D7.1 (K), D8.1 (K), D9.3, J5.5 (GND), SW1.1 (A), U3.2 (VSS), U4.12 (VSSA), U4.18 (VSS), U4.31 (VSS), U4.47 (VSS), U4.63 (VSS); also elsewhere on the board
I2C1_SCL: U4.58 (PB6); also elsewhere on the board
I2C1_SDA: U4.59 (PB7); also elsewhere on the board
IN_1: U4.43 (PA10); also elsewhere on the board
IN_2: U4.40 (PC9); also elsewhere on the board
unnamed: D7.2 (A), R8.2
unnamed: D8.2 (A), R9.2
unnamed: R10.1, SW1.2 (B)
unnamed: R10.2, U4.60 (BOOT0)
unnamed: R8.1, U4.8 (PC0)
unnamed: R9.1, U4.9 (PC1)
unnamed: TP4.1, U4.51 (PC10)
unnamed: TP3.1, U4.52 (PC11)
unnamed: TP2.1, U4.2 (PC13)
unnamed: C7.1, U4.5 (PH0), Y1.1
unnamed: C8.1, U4.6 (PH1), Y1.2
unnamed: C10.1, U4.30 (VCAP_1)
unnamed: FB1.2, U4.13 (VDDA)
PF_DEN1: U4.34 (PB13); also elsewhere on the board
PF_DEN2: U4.37 (PC6); also elsewhere on the board
PF_DEN3: U4.25 (PC5); also elsewhere on the board
PF_DEN4: U4.21 (PA5); also elsewhere on the board
PF_IN1: U4.35 (PB14); also elsewhere on the board
PF_IN2: U4.38 (PC7); also elsewhere on the board
PF_IN3: U4.26 (PB0); also elsewhere on the board
PF_IN4: U4.22 (PA6); also elsewhere on the board
PF_IS1: U4.11 (PC3); also elsewhere on the board
PF_IS2: U4.10 (PC2); also elsewhere on the board
PF_IS3: U4.14 (PA0); also elsewhere on the board
PF_IS4: U4.15 (PA1); also elsewhere on the board
USB_D+: U4.45 (PA12); also elsewhere on the board
USB_D-: U4.44 (PA11); also elsewhere on the board
USB_VBUS: U4.42 (PA9); also elsewhere on the board

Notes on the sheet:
SWD
Error
CAN Transceiver
HSE_OSC_IN
CL=18pF
HSE_OSC_OUT
VDDA
Status

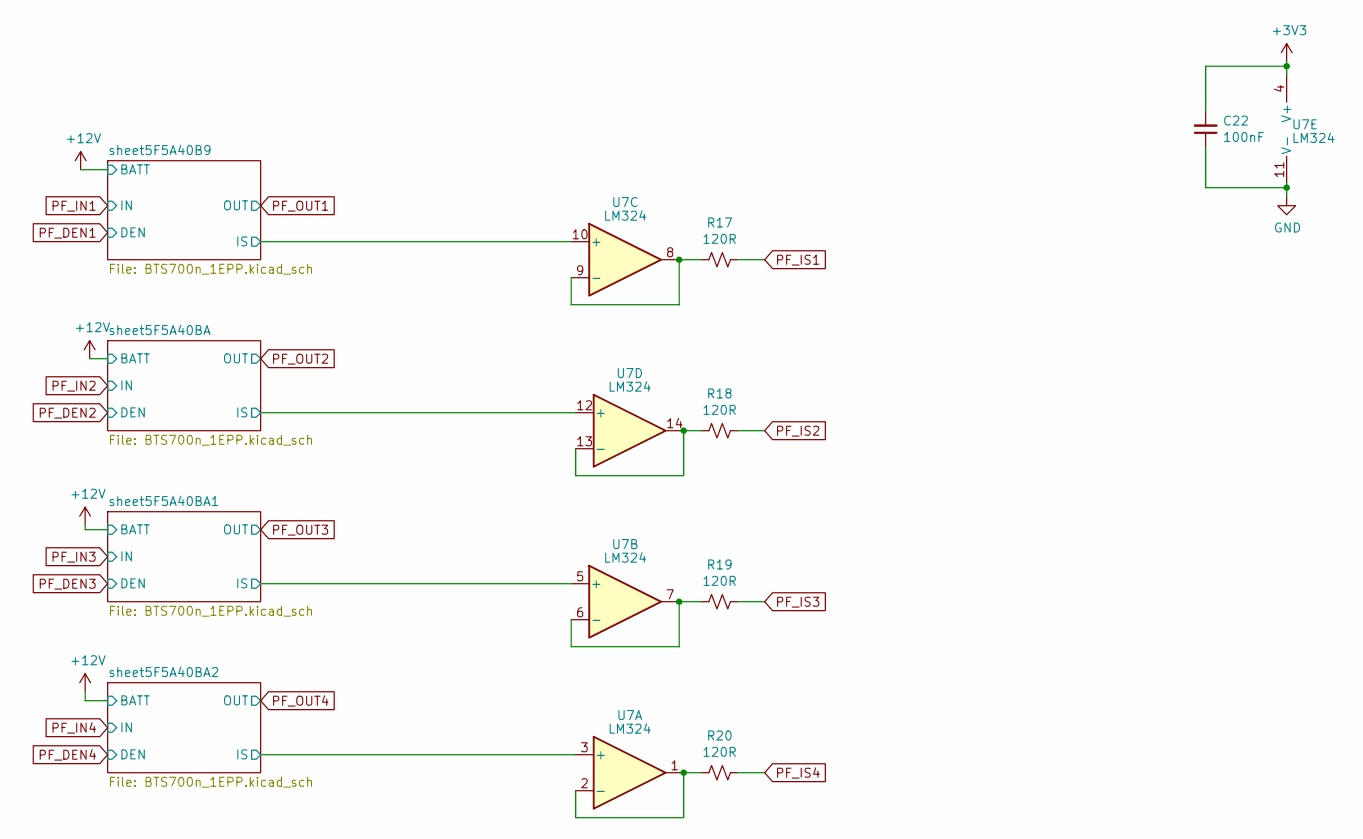
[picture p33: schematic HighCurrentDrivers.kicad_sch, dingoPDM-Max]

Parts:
C22: 100nF; C_0805_2012Metric; Digi-Key_PN 478-1395-1-ND
R17, R18, R19, R20: 120R; R_0805_2012Metric; Digi-Key_PN 311-120CRCT-ND
U7: LM324; TSSOP-14_4.4x5mm_P0.65mm; Digi-Key_PN 497-7330-1-ND

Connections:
+3V3: C22.2, U7.4 (V+); also elsewhere on the board
/HighCurrentDrivers/sheet5F5A40B9/IS: U7.10 (+); also elsewhere on the board
/HighCurrentDrivers/sheet5F5A40BA1/IS: U7.5 (+); also elsewhere on the board
/HighCurrentDrivers/sheet5F5A40BA2/IS: U7.3 (+); also elsewhere on the board
/HighCurrentDrivers/sheet5F5A40BA/IS: U7.12 (+); also elsewhere on the board
GND: C22.1, U7.11 (V-); also elsewhere on the board
unnamed: R20.2, U7.1, U7.2 (-)
unnamed: R19.2, U7.6 (-), U7.7
unnamed: R17.2, U7.8, U7.9 (-)
unnamed: R18.2, U7.13 (-), U7.14
PF_IS1: R17.1; also elsewhere on the board
PF_IS2: R18.1; also elsewhere on the board
PF_IS3: R19.1; also elsewhere on the board
PF_IS4: R20.1; also elsewhere on the board

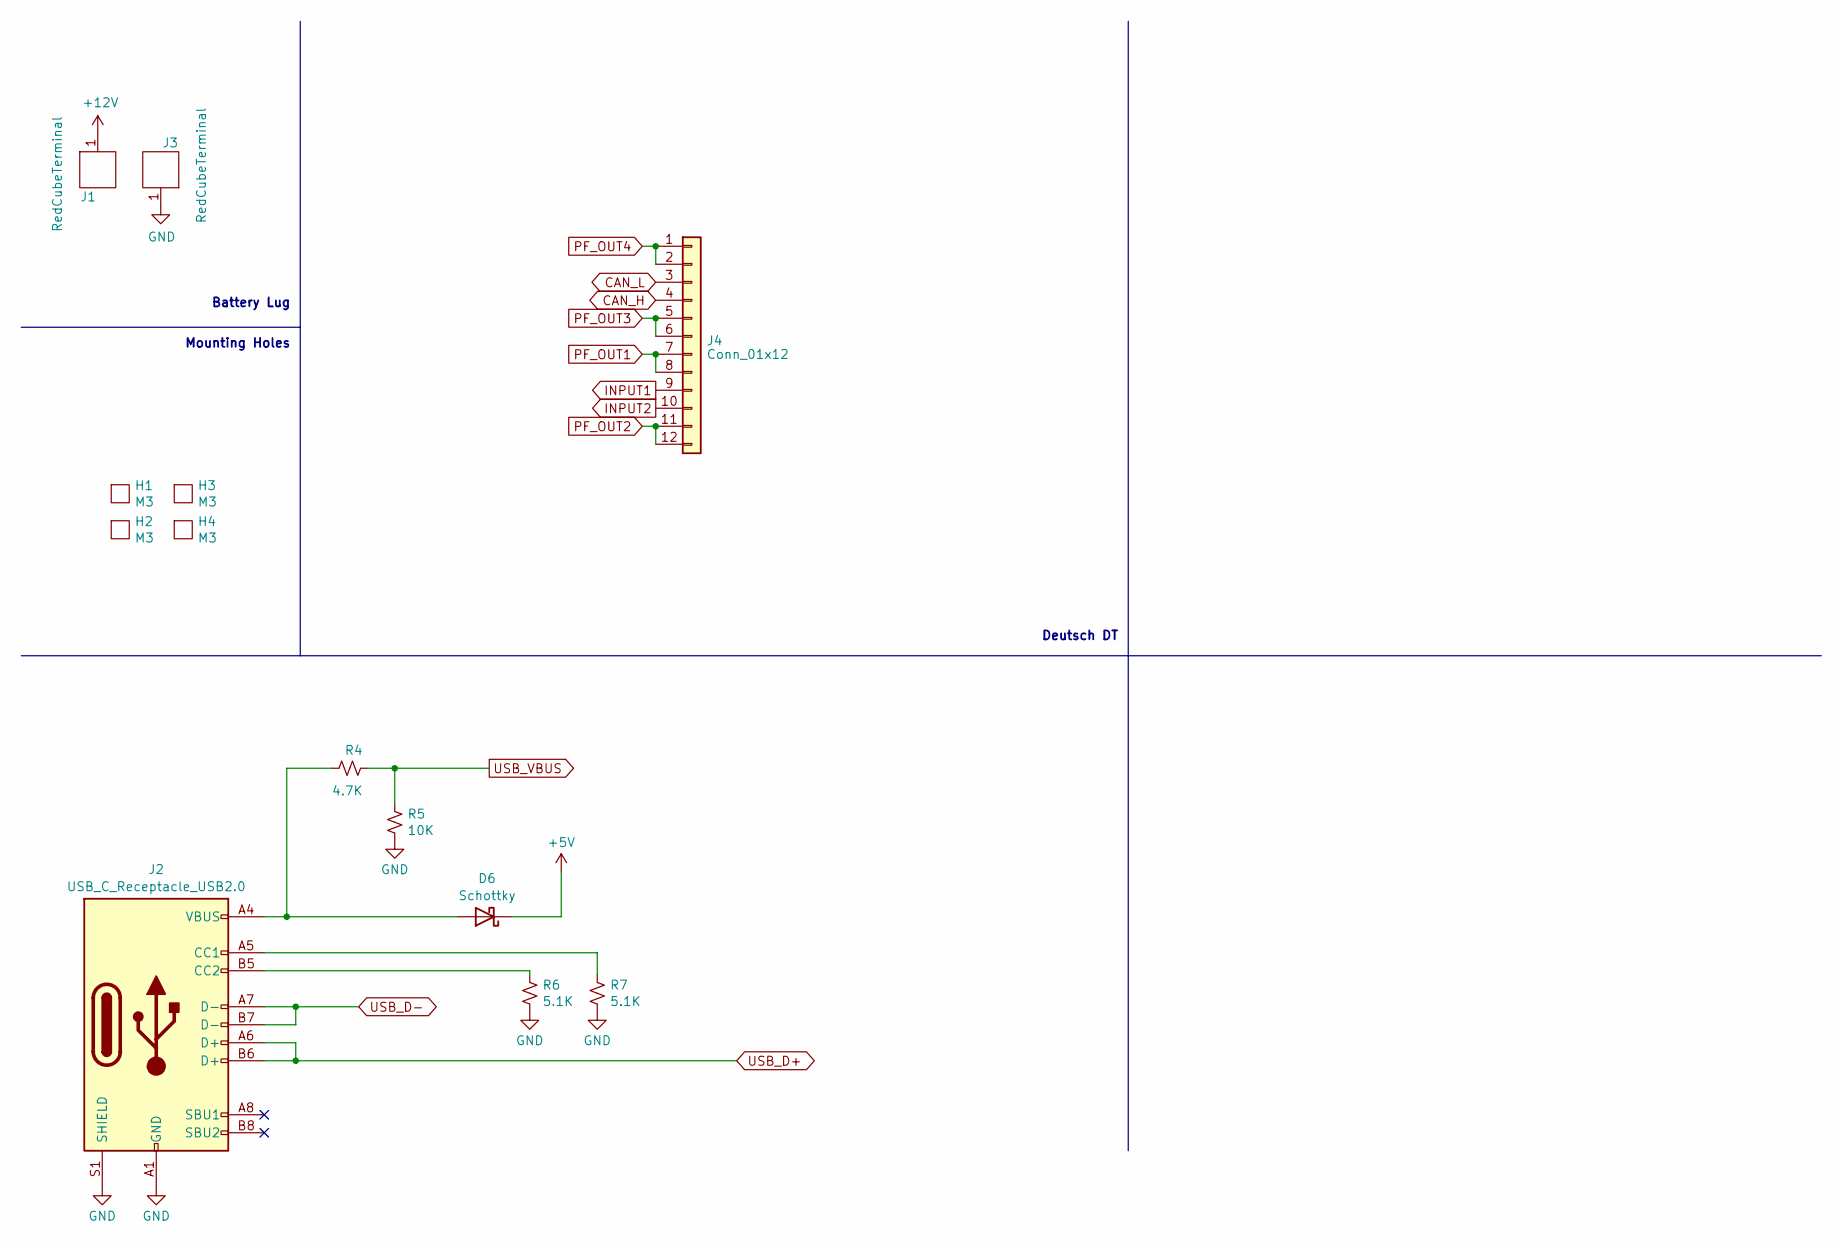
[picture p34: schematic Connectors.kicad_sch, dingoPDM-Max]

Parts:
D6: Schottky; D_SOD-123; Digi-Key_PN 1727-2394-1-ND
H1, H2, H3, H4: M3; MountingHole_3.2mm_M3_ISO7380_Pad
J1, J3: RedCubeTerminal; M6_Hole_8Pin_7461084; Digi-Key_PN 732-3203-ND
J2: USB_C_Receptacle_USB2.0; USB_C_Receptacle_GCT_USB4085; Digi-Key_PN 2073-USB4085-GF-ACT-ND
J4: Conn_01x12; DT15-12PA; LCSC C5341788
R4: 4.7K; R_0805_2012Metric; Digi-Key_PN 311-4.70KCRCT-ND
R5: 10K; R_0805_2012Metric; Digi-Key_PN 311-10.0KCRDKR-ND
R6, R7: 5.1K; R_0805_2012Metric; Digi-Key_PN 311-5.1KARCT-ND

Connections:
+5V: D6.1 (K); also elsewhere on the board
+12V: J1.1; also elsewhere on the board
CAN_H: J4.4; also elsewhere on the board
CAN_L: J4.3; also elsewhere on the board
GND: J2.A1 (GND), J2.A12 (GND), J2.B1 (GND), J2.B12 (GND), J2.S1 (SHIELD), J3.1, R5.2, R6.2, R7.2; also elsewhere on the board
INPUT1: J4.9; also elsewhere on the board
INPUT2: J4.10; also elsewhere on the board
unnamed: D6.2 (A), J2.A4 (VBUS), J2.A9 (VBUS), J2.B4 (VBUS), J2.B9 (VBUS), R4.1
unnamed: J2.A5 (CC1), R7.1
unnamed: J2.B5 (CC2), R6.1
PF_OUT1: J4.7, J4.8; also elsewhere on the board
PF_OUT2: J4.11, J4.12; also elsewhere on the board
PF_OUT3: J4.5, J4.6; also elsewhere on the board
PF_OUT4: J4.1, J4.2; also elsewhere on the board
USB_D+: J2.A6 (D+), J2.B6 (D+); also elsewhere on the board
USB_D-: J2.A7 (D-), J2.B7 (D-); also elsewhere on the board
USB_VBUS: R4.2, R5.1; also elsewhere on the board

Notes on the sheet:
Deutsch DT
Battery Lug
Mounting Holes

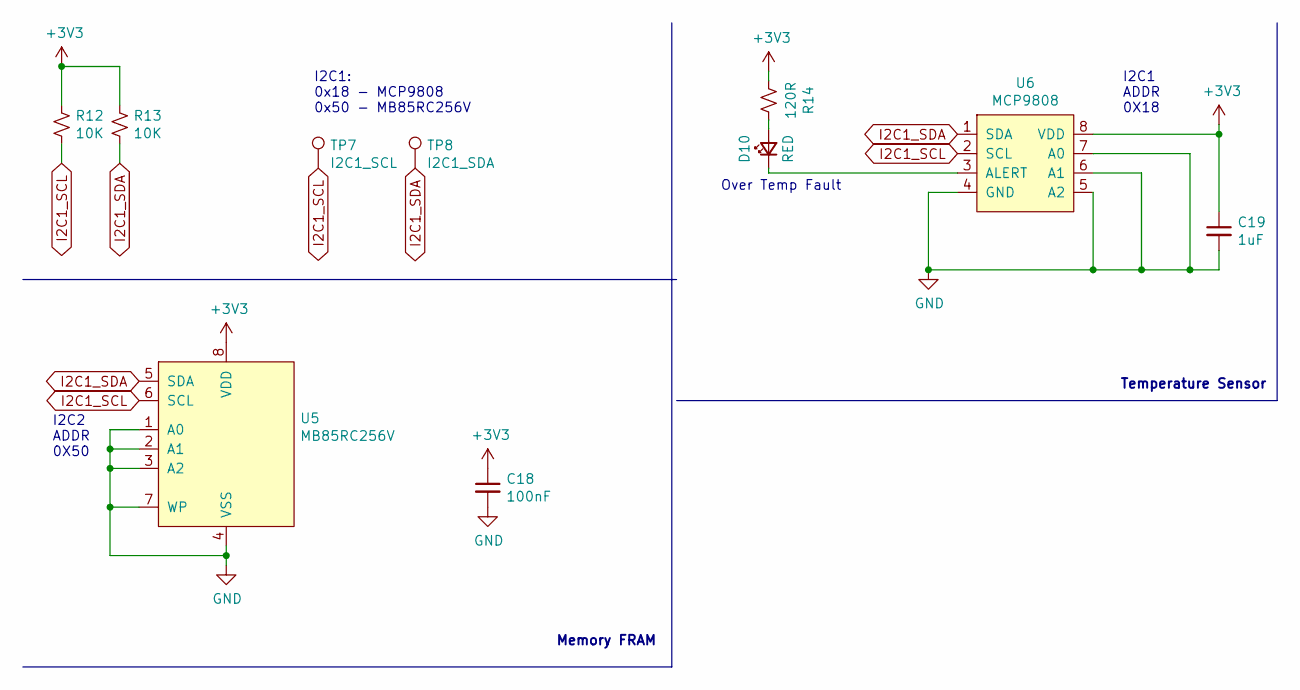
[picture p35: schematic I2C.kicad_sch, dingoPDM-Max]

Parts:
C18: 100nF; C_0805_2012Metric; Digi-Key_PN 478-1395-1-ND
C19: 1uF; C_0805_2012Metric; Digi-Key_PN 311-1365-1-ND
D10: RED; LED_0805_2012Metric; Digi-Key_PN 475-1278-1-ND
R12, R13: 10K; R_0805_2012Metric; Digi-Key_PN 311-10.0KCRDKR-ND
R14: 120R; R_0805_2012Metric; Digi-Key_PN 311-120CRCT-ND
TP7: I2C1_SCL; TestPoint_Keystone_5000-5004_Miniature
TP8: I2C1_SDA; TestPoint_Keystone_5000-5004_Miniature
U5: MB85RC256V; SOIC-8_3.9x4.9mm_P1.27mm; Digi-Key_PN 865-1261-1-ND
U6: MCP9808; MSOP-8_3x3mm_P0.65mm; Digi-Key_PN MCP9808T-E/MSCT-ND

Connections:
+3V3: C18.1, C19.1, R12.1, R13.1, R14.2, U5.8 (VDD), U6.8 (VDD); also elsewhere on the board
GND: C18.2, C19.2, U5.1 (A0), U5.2 (A1), U5.3 (A2), U5.4 (VSS), U5.7 (WP), U6.4 (GND), U6.5 (A2), U6.6 (A1), U6.7 (A0); also elsewhere on the board
I2C1_SCL: R12.2, TP7.1, U5.6 (SCL), U6.2 (SCL); also elsewhere on the board
I2C1_SDA: R13.2, TP8.1, U5.5 (SDA), U6.1 (SDA); also elsewhere on the board
unnamed: D10.2 (A), R14.1
unnamed: D10.1 (K), U6.3 (ALERT)

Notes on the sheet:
I2C1 ADDR 0X18
I2C2 ADDR 0X50
Over Temp Fault
Temperature Sensor
I2C1: 0x18 - MCP9808 0x50 - MB85RC256V
Memory FRAM

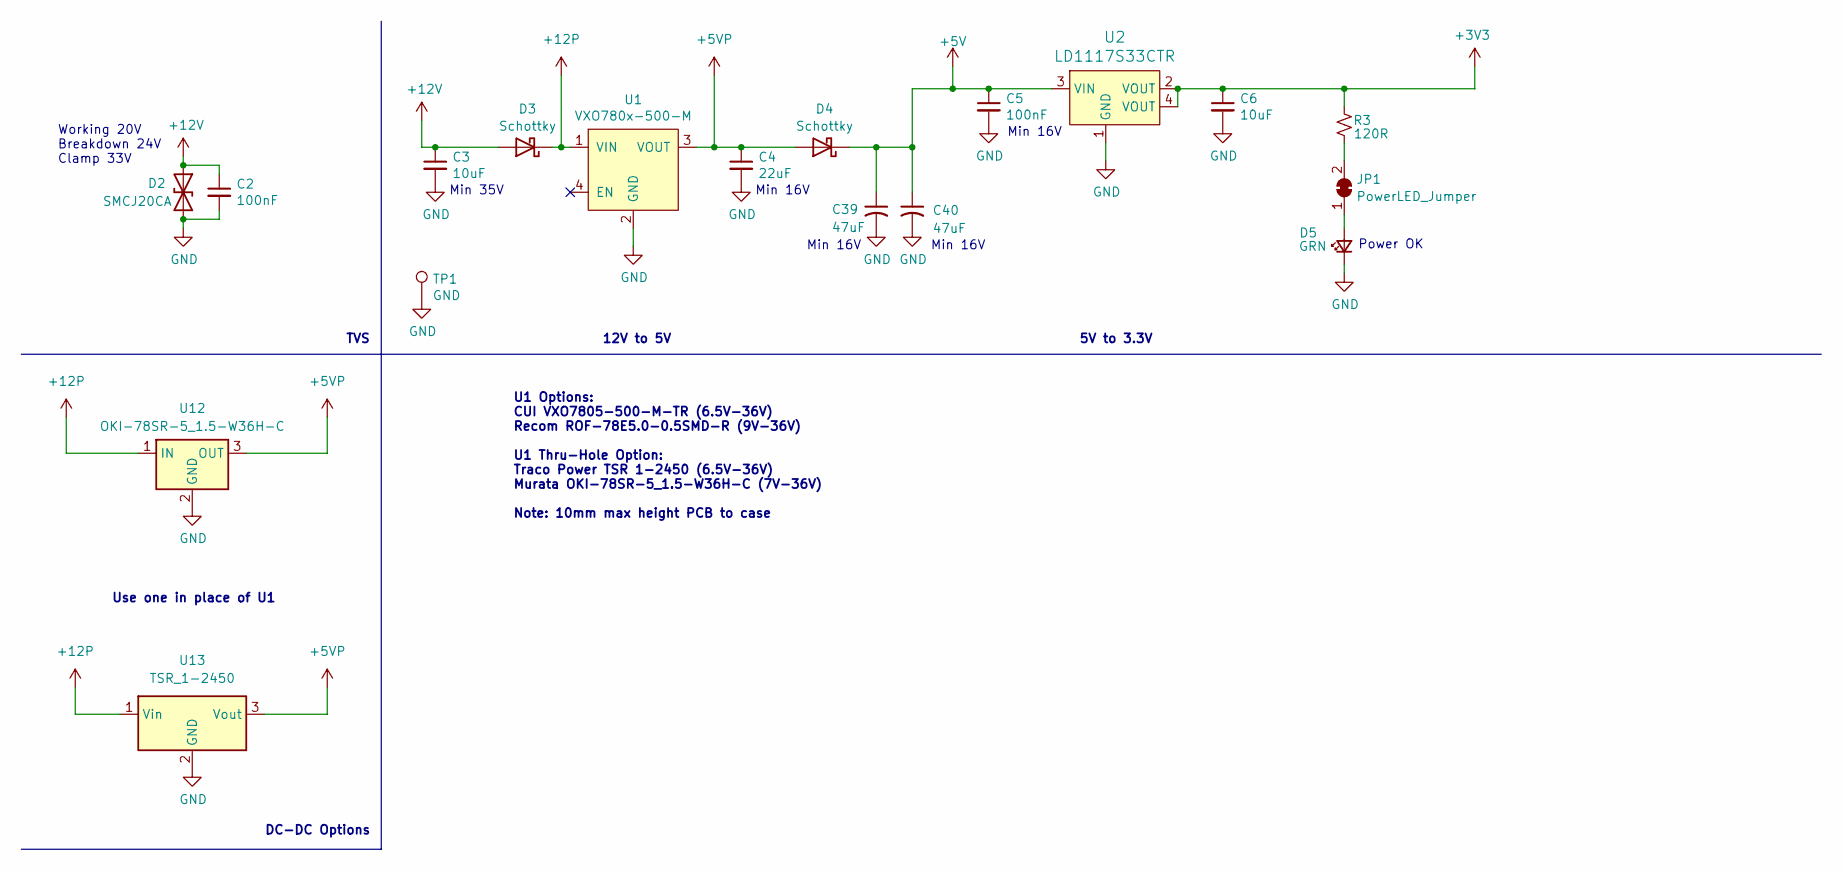
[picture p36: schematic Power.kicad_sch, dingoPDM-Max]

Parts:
C2, C5: 100nF; C_0805_2012Metric; Digi-Key_PN 478-1395-1-ND
C3, C6: 10uF; C_0805_2012Metric; Digi-Key_PN 445-11516-1-ND
C4: 22uF; C_0805_2012Metric; Digi-Key_PN 490-10749-1-ND
C39, C40: 47uF; C_2220_5750Metric; Digi-Key_PN 445-7935-1-ND
D2: SMCJ20CA; DO-214AB_TVS; Digi-Key_PN SMCJ20CABCT-ND
D3, D4: Schottky; D_SOD-123; Digi-Key_PN 1727-2394-1-ND
D5: GRN; LED_0805_2012Metric; Digi-Key_PN 475-1410-1-ND
JP1: PowerLED_Jumper; SolderJumper-2_P1.3mm_Bridged_RoundedPad1.0x1.5mm
R3: 120R; R_0805_2012Metric; Digi-Key_PN 311-120CRCT-ND
TP1: GND; TestPoint_Keystone_5000-5004_Miniature
U1: VXO780x-500-M; VXO78x-500-M; Digi-Key_PN 102-VXO7805-500-M-CT-ND
U2: LD1117S33CTR; SOT-223; Digi-Key_PN 497-1241-1-ND
U12: OKI-78SR-5_1.5-W36H-C; Converter_DCDC_Murata_OKI-78SR_Horizontal; Digi-Key_PN 811-2692-ND
U13: TSR_1-2450; Converter_DCDC_TRACO_TSR-1_THT; Digi-Key_PN 1951-2747-ND

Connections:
+3V3: C6.1, R3.2, U2.2 (VOUT), U2.4 (VOUT); also elsewhere on the board
+5V: C5.1, C39.1, C40.1, D4.1 (K), U2.3 (VIN); also elsewhere on the board
+5VP: C4.1, D4.2 (A), U1.3 (VOUT), U12.3 (OUT), U13.3 (Vout)
+12P: D3.1 (K), U1.1 (VIN), U12.1 (IN), U13.1 (Vin)
+12V: C2.1, C3.1, D2.1 (A1), D3.2 (A); also elsewhere on the board
GND: C2.2, C3.2, C4.2, C5.2, C6.2, C39.2, C40.2, D2.2 (A2), D5.1 (K), TP1.1, U1.2 (GND), U2.1 (GND), U12.2 (GND), U13.2 (GND); also elsewhere on the board
unnamed: D5.2 (A), JP1.1 (A)
unnamed: JP1.2 (B), R3.1

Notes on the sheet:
Min 16V
TVS
Min 35V
Power OK
Use one in place of U1
5V to 3.3V
12V to 5V
Working 20V Breakdown 24V Clamp 33V
DC-DC Options
U1 Options: CUI VXO7805-500-M-TR (6.5V-36V) Recom ROF-78E5.0-0.5SMD-R (9V-36V) U1 Thru-Hole Option: Traco Power TSR 1-2450 (6.5V-36V) Murata OKI-78SR-5_1.5-W36H-C (7V-36V) Note: 10mm max height PCB to case

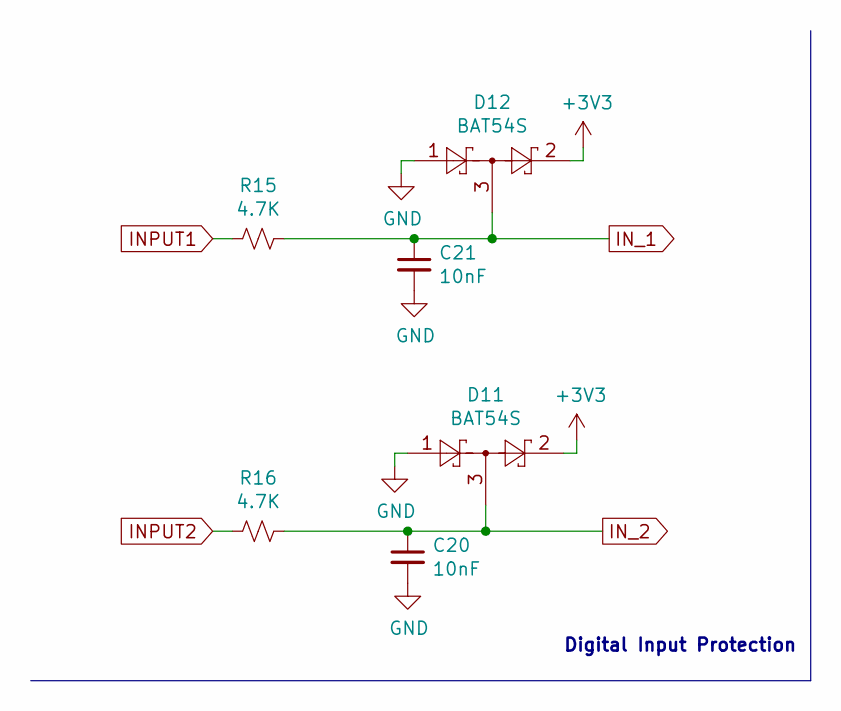
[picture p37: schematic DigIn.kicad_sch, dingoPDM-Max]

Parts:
C20, C21: 10nF; C_0805_2012Metric; Digi-Key_PN 311-1136-1-ND
D11, D12: BAT54S; SOT-23; Digi-Key_PN BAT54SLT1GOSCT-ND
R15, R16: 4.7K; R_0805_2012Metric; Digi-Key_PN 311-4.70KCRCT-ND

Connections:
+3V3: D11.2, D12.2; also elsewhere on the board
GND: C20.2, C21.2, D11.1, D12.1; also elsewhere on the board
INPUT1: R15.2; also elsewhere on the board
INPUT2: R16.2; also elsewhere on the board
IN_1: C21.1, D12.3, R15.1; also elsewhere on the board
IN_2: C20.1, D11.3, R16.1; also elsewhere on the board

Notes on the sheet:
Digital Input Protection

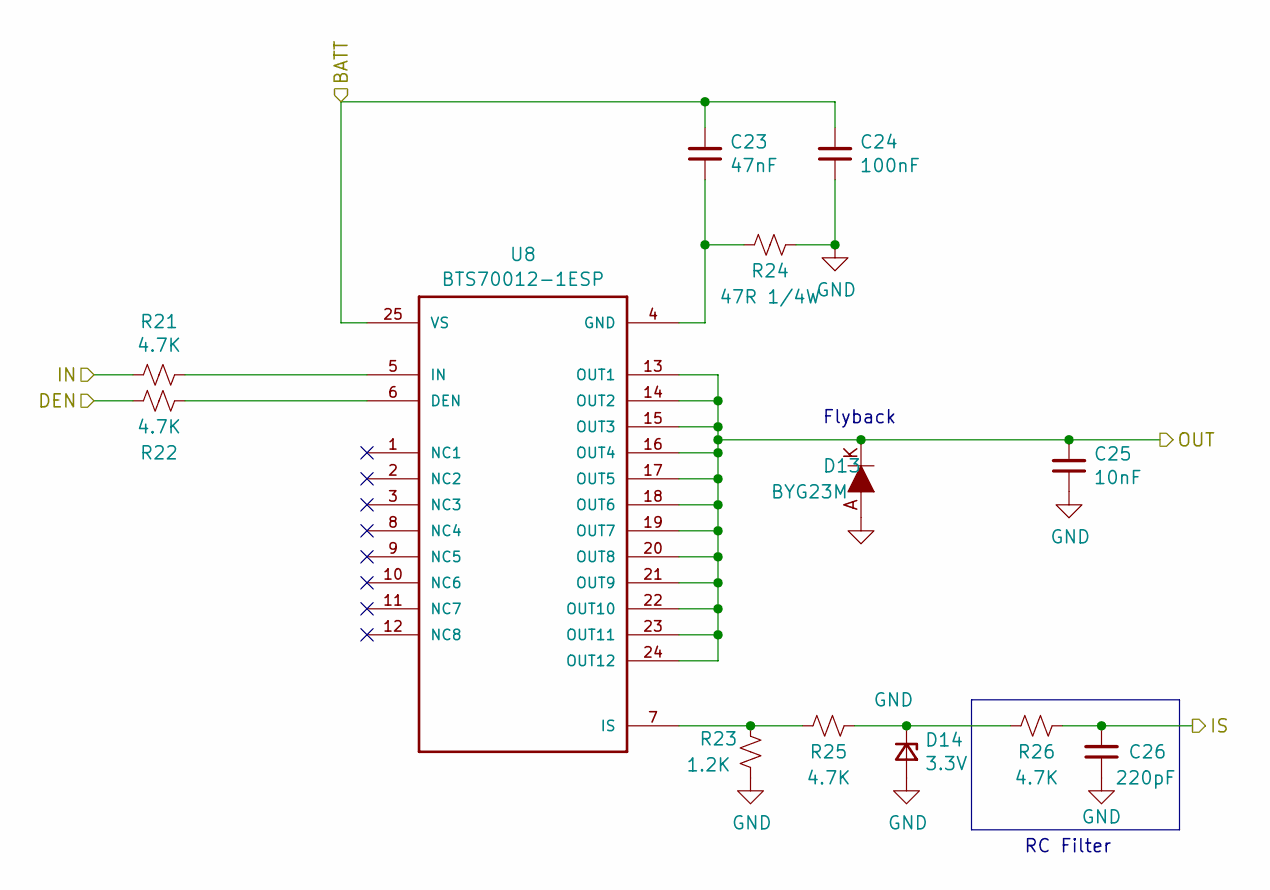
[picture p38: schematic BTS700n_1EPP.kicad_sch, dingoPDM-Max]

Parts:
C23: 47nF; C_0805_2012Metric; Digi-Key_PN 399-1166-1-ND
C24: 100nF; C_0805_2012Metric; Digi-Key_PN 478-1395-1-ND
C25: 10nF; C_0805_2012Metric; Digi-Key_PN 311-1136-1-ND
C26: 220pF; C_0805_2012Metric; Digi-Key_PN 399-1138-1-ND
D13: BYG23M; DO-214AC; Digi-Key_PN BYG23M-E3/TR3GICT-ND
D14: 3.3V; D_SOD-323_HandSoldering; Digi-Key_PN 1727-5150-1-ND
R21, R22, R25, R26: 4.7K; R_0805_2012Metric; Digi-Key_PN 311-4.70KCRCT-ND
R23: 1.2K; R_0805_2012Metric; Digi-Key_PN 311-1.20KCRCT-ND
R24: 47R 1/4W; R_1206_3216Metric; Digi-Key_PN 311-47.0FRCT-ND
U8: BTS70012-1ESP; TSDSO-24; Digi-Key_PN 448-BTS700121ESPXUMA2CT-ND

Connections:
+12V: C23.2, C24.2, U8.25 (VS); also elsewhere on the board
/HighCurrentDrivers/sheet5F5A40B9/IS: C26.2, R26.1; also elsewhere on the board
GND: C24.1, C25.1, C26.1, D13.A, D14.2 (A), R23.2, R24.1; also elsewhere on the board
unnamed: D14.1 (K), R25.1, R26.2
unnamed: R22.1, U8.6 (DEN)
unnamed: C23.1, R24.2, U8.4 (GND)
unnamed: R21.1, U8.5 (IN)
unnamed: R23.1, R25.2, U8.7 (IS)
PF_DEN1: R22.2; also elsewhere on the board
PF_IN1: R21.2; also elsewhere on the board
PF_OUT1: C25.2, D13.K, U8.13 (OUT1), U8.14 (OUT2), U8.15 (OUT3), U8.16 (OUT4), U8.17 (OUT5), U8.18 (OUT6), U8.19 (OUT7), U8.20 (OUT8), U8.21 (OUT9), U8.22 (OUT10), U8.23 (OUT11), U8.24 (OUT12); also elsewhere on the board

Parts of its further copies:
C27, C31, C35: 47nF; C_0805_2012Metric; Digi-Key_PN 399-1166-1-ND
C28, C32, C36: 100nF; C_0805_2012Metric; Digi-Key_PN 478-1395-1-ND
C29, C33, C37: 10nF; C_0805_2012Metric; Digi-Key_PN 311-1136-1-ND
C30, C34, C38: 220pF; C_0805_2012Metric; Digi-Key_PN 399-1138-1-ND
D15, D17, D19: BYG23M; DO-214AC; Digi-Key_PN BYG23M-E3/TR3GICT-ND
D16, D18, D20: 3.3V; D_SOD-323_HandSoldering; Digi-Key_PN 1727-5150-1-ND
R27, R28, R31, R32, R33, R34, R37, R38, R39, R40, R43, R44: 4.7K; R_0805_2012Metric; Digi-Key_PN 311-4.70KCRCT-ND
R29, R35, R41: 1.2K; R_0805_2012Metric; Digi-Key_PN 311-1.20KCRCT-ND
R30, R36, R42: 47R 1/4W; R_1206_3216Metric; Digi-Key_PN 311-47.0FRCT-ND
U9, U10, U11: BTS70012-1ESP; TSDSO-24; Digi-Key_PN 448-BTS700121ESPXUMA2CT-ND

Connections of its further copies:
+12V: C27.2, C28.2, C31.2, C32.2, C35.2, C36.2, U9.25 (VS), U10.25 (VS), U11.25 (VS); also elsewhere on the board
/HighCurrentDrivers/sheet5F5A40BA1/IS: C34.2, R38.1; also elsewhere on the board
/HighCurrentDrivers/sheet5F5A40BA2/IS: C38.2, R44.1; also elsewhere on the board
/HighCurrentDrivers/sheet5F5A40BA/IS: C30.2, R32.1; also elsewhere on the board
GND: C28.1, C29.1, C30.1, C32.1, C33.1, C34.1, C36.1, C37.1, C38.1, D15.A, D16.2 (A), D17.A, D18.2 (A), D19.A, D20.2 (A), R29.2, R30.1, R35.2, R36.1, R41.2, R42.1; also elsewhere on the board
unnamed: D16.1 (K), R31.1, R32.2
unnamed: D18.1 (K), R37.1, R38.2
unnamed: D20.1 (K), R43.1, R44.2
unnamed: R28.1, U9.6 (DEN)
unnamed: C27.1, R30.2, U9.4 (GND)
unnamed: R27.1, U9.5 (IN)
unnamed: R29.1, R31.2, U9.7 (IS)
unnamed: R34.1, U10.6 (DEN)
unnamed: C31.1, R36.2, U10.4 (GND)
unnamed: R33.1, U10.5 (IN)
unnamed: R35.1, R37.2, U10.7 (IS)
unnamed: R40.1, U11.6 (DEN)
unnamed: C35.1, R42.2, U11.4 (GND)
unnamed: R39.1, U11.5 (IN)
unnamed: R41.1, R43.2, U11.7 (IS)
PF_DEN2: R28.2; also elsewhere on the board
PF_DEN3: R34.2; also elsewhere on the board
PF_DEN4: R40.2; also elsewhere on the board
PF_IN2: R27.2; also elsewhere on the board
PF_IN3: R33.2; also elsewhere on the board
PF_IN4: R39.2; also elsewhere on the board
PF_OUT2: C29.2, D15.K, U9.13 (OUT1), U9.14 (OUT2), U9.15 (OUT3), U9.16 (OUT4), U9.17 (OUT5), U9.18 (OUT6), U9.19 (OUT7), U9.20 (OUT8), U9.21 (OUT9), U9.22 (OUT10), U9.23 (OUT11), U9.24 (OUT12); also elsewhere on the board
PF_OUT3: C33.2, D17.K, U10.13 (OUT1), U10.14 (OUT2), U10.15 (OUT3), U10.16 (OUT4), U10.17 (OUT5), U10.18 (OUT6), U10.19 (OUT7), U10.20 (OUT8), U10.21 (OUT9), U10.22 (OUT10), U10.23 (OUT11), U10.24 (OUT12); also elsewhere on the board
PF_OUT4: C37.2, D19.K, U11.13 (OUT1), U11.14 (OUT2), U11.15 (OUT3), U11.16 (OUT4), U11.17 (OUT5), U11.18 (OUT6), U11.19 (OUT7), U11.20 (OUT8), U11.21 (OUT9), U11.22 (OUT10), U11.23 (OUT11), U11.24 (OUT12); also elsewhere on the board

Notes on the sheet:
RC Filter
Flyback

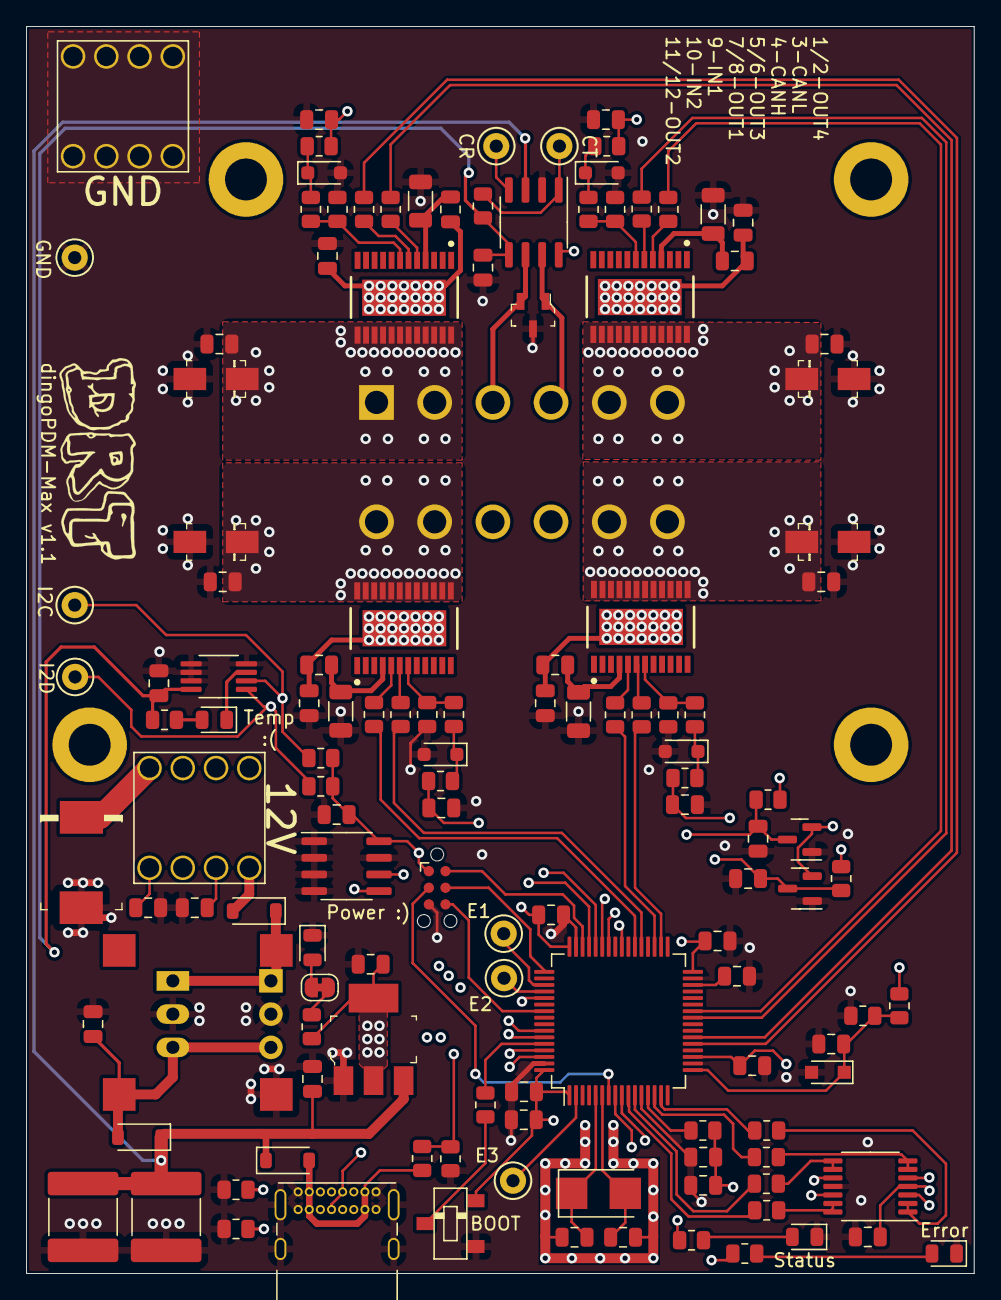
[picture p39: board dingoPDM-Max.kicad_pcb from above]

Board: 4 copper layers, 72.4 x 95.2 mm, 140 parts (1 on the bottom side), 89 nets.

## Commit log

2024-07-14 Initial design
    [7461084_Download_STP_7461084_rev1.stp, ABM3.STEP, Analog.sch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]
2024-07-16 First layout complete
    [dingoPDM-Max.kicad_pcb]
2024-09-06 Updated to Kicad 8
    [BTS700n_1EPP.kicad_sch, Connectors.kicad_sch, DigIn.kicad_sch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]
2024-09-06 Another updated Kicad 8 file
    [dingoPDM-Max.kicad_pcb]
2024-09-07 First version ordered
    [BTS700n_1EPP.kicad_sch, Baseplate.step, Case.step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]
2025-06-17 add dc-dc options and 5v cap
    [BTS700n_1EPP.kicad_sch, Connectors.kicad_sch, DigIn.kicad_sch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]
2025-06-17 add exports
    [Baseplate.step, Case.step, DingoPDM_V7_WiringAid.stl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]
2025-06-17 switch to ceramic caps
    [Connectors.kicad_sch, Power.kicad_sch, dingoPDM-Max.kicad_pcb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]
2025-09-30 fixed bad zone, shifted traces, increase trace widths
    update part numbers for ibom
    [BTS700n_1EPP.kicad_sch, Connectors.kicad_sch, DigIn.kicad_sch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]
2025-09-30 add v1.2 export
    [Baseplate.step, Case.step, DingoPDM_V7_WiringAid.stl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]
2026-09-26 kicad v10 update
    [BTS700n_1EPP.kicad_sch, Connectors.kicad_sch, DigIn.kicad_sch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]
2026-09-26 fix tvs jlc pn, #25
    [Power.kicad_sch]

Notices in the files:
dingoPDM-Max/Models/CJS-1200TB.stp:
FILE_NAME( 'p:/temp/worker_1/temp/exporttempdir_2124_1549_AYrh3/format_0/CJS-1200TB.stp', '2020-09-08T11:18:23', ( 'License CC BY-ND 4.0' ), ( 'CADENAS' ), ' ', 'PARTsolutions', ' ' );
